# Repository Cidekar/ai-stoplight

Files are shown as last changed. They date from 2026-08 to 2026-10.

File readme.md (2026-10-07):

# Stoplight

**Stop alt-tabbing to see if your agent is done.**

```
        ╭───────────╮
        │           │
        │    ( ● )  │  ← RED     needs you
        │           │
        │    (   )  │    yellow  working
        │           │
        │    (   )  │    green   done
        │           │
        ├───────────┤
        │ ▪ ● · ·   │
        │ auth-api  │  ← which job is waiting
        ╰───────────╯
```

A small traffic light that sits on your desk and tells you, without you looking for it, exactly what every AI coding session is doing.

You know the loop. You give an agent a task, switch to something else, and then spend the next ten minutes half-wondering. You tab back. Still thinking. You tab back again. It finished four minutes ago and has been waiting on a yes.

Stoplight ends that. The answer is on your desk, in your peripheral vision, in a colour you can read from across the room.

**It is not tied to any one AI tool.** Stoplight speaks [an open protocol](rfc.md): four events over one HTTP endpoint. Claude Code, Codex, Gemini CLI, Cursor, Aider, DeepSeek, Kimi, an agent you wrote this morning, or a build that takes twenty minutes — if it can make a web request, it can drive the light. Claude Code ships with an adapter because it was first, not because it is special.

## Why you want one

**It uses the eye you are not using.** A notification competes with your screen. A light on your desk does not. You catch red the way you catch a car's brake lights, without deciding to look.

**It knows which project.** Three sessions running, one goes red. The screen below the lamps tells you it is `auth-api`, not the refactor you actually care about. Names scroll, the screen rotates, and one button pins whichever one you are watching.

**It never lies to you.** The lamp always shows the most urgent state across every session. Pin the screen, walk away, come back — if anything needs you, it is still red.

**You build it in an evening.** One board the size of a stamp, three LEDs, a battery. The case prints in four parts. No soldering iron heroics required.

**It runs itself.** One install command, then it starts with your laptop and stays out of your way. No terminal window to babysit.

**It is not tied to one vendor.** Four events over HTTP is the whole integration. If your agent can make a web request, it can drive the light.

## How it works

Three pieces, and you only ever touch the first one.

```
   ANY PRODUCER               RELAY                     THE LIGHT
   ────────────               ─────                     ─────────
   any LLM CLI ──┐
   your agent  ──┤                        USB        ┌───────────┐
   a test suite──┼── HTTP ──▶  one Go   ─serial─▶    │  ( ● )    │
   a slow build──┤             binary                │  (   )    │
   a deploy    ──┘             tracks   ╌╌╌BLE╌╌▶    │  (   )    │
                               every     or wired    │ auth-api  │
     "I am working"            session               └───────────┘
     "I need a human"          at once                on your desk
     "I am done"
```

USB serial and BLE both work. The relay auto-discovers a USB light, and `--ble` runs it against a Bluetooth light instead. The two transports sit behind one interface, so a producer sees no difference either way.

Nothing in that left column is privileged. They all send the same four events to the same endpoint, and the relay weighs them identically.

**Your agent reports what happened.** Four events: started, blocked, finished, ended. Nothing else. It never picks a colour, because it cannot know what else is running.

**One small Go binary decides what matters.** It tracks every session from every tool at once and resolves them to a single answer. Red beats yellow beats green, always. No web server to configure, no database, no config file to hand-write.

**The light does the telling.** Awake the moment something changes. It connects over USB serial or BLE, so you can wire it or run it from the battery.

Here is one moment, end to end:

```
   your agent hits a permission prompt
                  │
                  ▼
      POST {"event":"blocked",          ● RED
            "label":"auth-api"}   ──▶   + "auth-api" on screen
                  │
                  ▼
   you glance up, already know which job, and act
```

Unplug the light, kill the relay — your work never notices. Every client discards errors by design. The light is an accessory, never a dependency.

## Works with anything

Three ways in, depending on what your tool gives you.

| Your tool | What you do |
|---|---|
| Has a hook or plugin system | Use an adapter, or write one. `stoplight install` sets it up. |
| You can run a command around it | Wrap it in five lines of shell |
| You wrote it yourself | Post directly at the points where you know your state |

**With an adapter.** Claude Code ships with one, so `stoplight install` wires it up and you are done. Adapters for other tools are the most welcome contribution to this project.

**By wrapping.** Works for any command, including ones with no hooks at all. Yellow while it runs, green if it succeeds, red if it does not:

```bash
stoplight_run() {
  local id="wrap:$$" label="${PWD##*/}"
  _sl() { curl -s -m 0.25 -X POST http://127.0.0.1:7373/v1/session \
    -H 'Content-Type: application/json' \
    -d "{\"session_id\":\"$id\",\"event\":\"$1\",\"label\":\"$label\"}" \
    >/dev/null 2>&1 || true; }
  _sl started; "$@"; local rc=$?
  [ $rc -eq 0 ] && _sl finished || _sl blocked
  return $rc
}

stoplight_run my-agent --do-the-thing
stoplight_run make integration-test
```

**By posting directly.** One request, no library, no dependency:

```bash
curl -s -m 0.25 -X POST http://127.0.0.1:7373/v1/session \
  -H 'Content-Type: application/json' \
  -d '{"session_id":"job-1","event":"blocked","label":"auth-api"}' || true
```

That is the entire integration surface. The `|| true` is deliberate and it is the rule for every client: if the light is unreachable, your work carries on as though nothing happened.

Full specification in [RFC 1](rfc.md), with reference clients in shell, Python and Go.

## Setup

```
stoplight install     # adapters for what you have, plus a service at login
```

One command. It wires up an adapter for every agent built into the binary, installs a background service, and starts it. `stoplight uninstall` reverses all of it. Both are idempotent, so running them twice changes nothing. Pass `--ble` or `--ble-name <name>` to pin the service to a Bluetooth light.

For Claude Code that means five hook entries in `~/.claude/settings.json`. For anything else, point it at the endpoint and there is nothing to install at all.

After that the light works without you thinking about it. `stoplight` on its own runs the relay in the foreground, which is what you want while developing or debugging, but the service means you never have to.

## Running as a service

A light that needs a terminal window open is a light you will forget to start. The relay therefore runs as a background service that survives logout, reboot and crashes.

Each platform has one obvious mechanism, and Stoplight uses it rather than shipping its own daemon manager.

| Platform | Mechanism | Location |
|---|---|---|
| macOS | launchd user agent | `~/Library/LaunchAgents/com.stoplight.relay.plist` |
| Linux | systemd user unit | `~/.config/systemd/user/stoplight.service` |
| Windows | Scheduled task, at logon | Task Scheduler |

All three are user-level, not system-level. The relay needs no privileges, it needs your session's access to the USB device, and a user service starts when you log in rather than at boot. Installing to the system would ask for a password and gain nothing.

`RunAtLoad` and `KeepAlive` are both set on macOS, with the equivalents elsewhere. If the relay crashes, the service manager restarts it. If the light is unplugged, the relay stays up and keeps retrying rather than exiting, because exiting would look identical to a crash.

Logs go to `~/.local/state/stoplight/stoplight.log`, or the platform equivalent. The relay records lifecycle events: when it starts listening, when the light connects or drops and reconnects, when a poll or a send fails, and when an ingest is rejected. A successful event is not logged line by line, because that would fill the file on a busy desk. The service appends to that one file and nothing rotates it yet, so truncate it yourself if it grows. Rotation is planned.

### Managing it

| Command | What it does |
|---|---|
| `stoplight status` | Service state, light connection, session count and aggregate |
| `stoplight restart` | Bounce the service |
| `stoplight logs` | Tail the log |
| `stoplight service stop` | Stop until next login |
| `stoplight service disable` | Stop and do not start at login |

These wrap the platform tool rather than replacing it. `launchctl` and `systemctl` still work directly if you prefer them, and `stoplight status` prints the underlying command it used so the wrapper is never a black box.

### Producers and the relay are independent

Producers post and forget. If the relay is not running, the post fails and the producer carries on. `stoplight notify` exits 0 on every path, and the reference clients in RFC 1 discard errors deliberately.

That independence matters during upgrades and crashes. Your agent keeps working whether or not the light does, and the relay can be restarted underneath a running session without losing anything except the moments it was down.

Recovery runs one way only: from the relay down to the light. The relay holds the session set in memory and re-sends the current frame the moment the light comes back, so the lamps catch up without anyone asking the producers for anything. The relay never calls back to a producer, because it holds no address for one. That is also the limit of the recovery: restart the relay itself and the session set is gone, and each session reappears only when its producer next reports. [RFC 1 §7](rfc.md#7-session-lifecycle) asks long-running agents to re-send their state every few minutes for exactly this reason.

## Events

A producer reports what happened. It never picks a colour, because it cannot know what else is running. Four events cover everything:

| Event | Colour | Meaning |
|---|---|---|
| `started` | Yellow | Working |
| `blocked` | Red | Needs a human |
| `finished` | Green | Done |
| `ended` | — | Stop tracking this session |

The distinction that carries the whole product is `blocked` versus `started`. Send `blocked` when a human has to act before anything continues. Send `started` when the agent is thinking or running tools on its own.

### Claude Code

The adapter maps Claude Code's hooks onto those events. This is the only place a vendor's vocabulary appears:

| Claude Code hook | Matcher | Event |
|---|---|---|
| `SessionStart` | `startup` | `idle` |
| `UserPromptSubmit` | | `started` |
| `PreToolUse` | | `started` |
| `Notification` | `permission_prompt` | `blocked` |
| `Stop` | | `finished` |
| `SessionEnd` | | `ended` |

The matcher keeps a hook to the sub-event that means the event. `SessionStart` fires on more than a fresh start, so it is pinned to `startup`, or an auto-compaction mid-turn would read as idle. `Notification` fires on more than a permission prompt, so it is pinned to `permission_prompt`, or a routine idle reminder would turn the light red. `PreToolUse` carries the `started` that clears `blocked`: after you approve a prompt the agent runs a tool, and this is what returns the session to working before the turn ends.

`SessionEnd` is what makes a closed session leave the light. It fires on exit, on Ctrl-D and on abnormal termination.

Adding another agent is a new adapter, or no adapter at all if it can post directly. See [RFC 1 §10](rfc.md#10-adapters).

#### Hooks report changes, a poll fills the gaps

The hooks are edge-triggered: they fire on a transition, never on a state. On their own they miss two things. A session that was open before the relay started has no transition to announce itself with. A window that is killed with `kill -9`, a closed terminal or a crash skips `Stop` and `SessionEnd`, so the session stays in the relay at whatever colour it held.

The Claude Code adapter closes both gaps with a poll. It reads `claude agents --json` every twenty seconds and declares the whole live set to the relay as a sync, per [RFC 1 §5.4](rfc.md#54-the-sync-endpoint). A session the agent already runs appears in the next poll and the light learns it exists. A session that vanished without a final event is absent from the next poll and the relay ends it. One poll after a relay restart restores the whole picture.

The poll corrects, it does not replace the hooks. A hook moves the lamp the instant something changes, which is the whole point of the device. The poll runs on its own schedule and never sits on the hook path. See [RFC 1 §10.1](rfc.md#101-discovery-mechanisms).

For a producer that only reports and cannot be polled, a stale red session clears by hand. Sessions carry a `last_seen` timestamp, visible in `GET /v1/status`, so a stale entry is the one whose `last_seen` stopped moving. End it with its id:

```bash
curl -s -X POST http://127.0.0.1:7373/v1/session \
  -H 'Content-Type: application/json' \
  -d '{"session_id":"<the stale id>","event":"ended"}'
```

Restarting the relay also clears everything, since the session set lives in memory.

## State model

All sessions share one light, whatever produced them, and the most urgent state wins.

```
red  >  yellow  >  green
```

If any session needs a human, the light is red. Otherwise, if any session is working, the light is yellow. Otherwise it is green. No live sessions at all means the lamps are off, because green means finished and off means nothing is running.

The relay tracks each session separately and computes the aggregate. A Claude Code session and a shell script are weighted identically; the light does not care which tool asked. Sessions that end are dropped, and a session that goes quiet expires after 30 minutes so one crash cannot hold the light red forever.

## Task display

The lamps tell you the state. The screen tells you which job that state belongs to. This matters as soon as you run more than one session, because a red light with no context does not say which project is waiting on you.

A producer can send a label. If it does not, the relay derives one.

```
·
auth-api
```

The header is a row of dots, one per session, with the current one filled. Below it the screen draws the label. The screen carries no state word, because the lamps already say the state in colour from across the room. The derived label is the git branch of the session's working directory, falling back to the directory name, then the provider name, then the session ID. Branches are usually named after the work, so this is free and it is usually right. A detached HEAD has no branch name, so it falls through to the directory name like any other case.

A producer can send its own instead, and you can override any session by hand.

```
stoplight task --session-id <id> "nightly integration run"
stoplight task --session-id <id> --clear
```

That overrides the label until the session ends or you clear it. `--clear` removes the override, so the derived label shows again.

The session ID is not optional. There is no "current session" concept yet, because nothing tells the CLI which of your sessions the terminal you are typing in belongs to, so the command asks you which one you mean. `stoplight status` prints a session count, not the ids; read the ids from `GET /v1/status`, which lists each session with its `id`.

### Rotation

With more than one session running, the screen cycles through them. Each session gets the screen for at least three seconds, then the display advances.

Order is by session start time, so a session keeps its place in the cycle as others come and go. A single session does not rotate, because a cycle of one is a static screen that redraws for no reason. The row of dots in the header shows position in the set: one dot per session, the current one filled. The shape of the row says both how many sessions there are and where you are in the cycle, without the eye reading two digits.

```
▪  ● · · ·
stoplight
```

Two rules keep rotation from hiding things.

The lamps never rotate. They always show the aggregate of every session, so a red lamp means something needs you even while the screen displays a green session. The lamp answers whether anything wants attention and the screen answers what is running. Those are different questions and the device answers both at once.

When a session turns red, the screen jumps to it immediately and holds for a full interval before resuming the cycle. The moment something needs you is the moment you want to know which project it is.

### Scrolling

The label line holds about eight characters, which is narrower than many branch names. Labels that do not fit scroll.

Scrolling is a marquee, not a loop. The label holds at the start for a second, scrolls left at a readable rate, holds at the end, then resets. A continuous wrap-around never gives a stable moment to read the first characters, which is where the useful part of a branch name usually is.

Two limits keep it calm. Labels that already fit are drawn statically and never move. Scrolling resets to the start whenever the session changes colour.

Rotation waits for scrolling. The three second interval is a minimum, not a fixed period, so a slot holds until its label has finished scrolling and then advances. Rotation therefore runs slightly irregularly, paced by content rather than a clock.

Before scrolling, the app strips common prefixes from the derived label. `feature/`, `bugfix/`, `hotfix/` and `worktree-` carry no information when every branch has one. `worktree-stoplight-readme` becomes `stoplight-readme`, which is shorter and more distinct.

### Button

One button on the case, wired to a spare GPIO and ground, using the internal pull-up. Firmware debounces it over about 50ms.

| Press | Action |
|---|---|
| Short, under 500ms | Pin or unpin the session on screen |
| Long, 500ms or more | Advance to the next session |

Pinning stops the rotation on the current session. Scrolling continues, because a pinned label still needs to be readable. A marker in the corner shows the pin.

A pin releases itself. It clears when that session ends, and it clears after a timeout even if the session is still alive. Without expiry you could pin something on a Monday, forget, and quietly stop seeing every other session for a week.

Pinning changes the screen and never the lamps. A pinned green session with a red session running still gives a red lamp. The pin must not be able to hide an alert.

The pin lives in the firmware, so it survives a dropped link and reconnection over either transport. It is a property of the device rather than of the session list, which is what lets it survive a dropped BLE link too.

Long press was chosen over a double tap. A double tap needs a timing window between presses, and pressing a button set into a small case rocks the case on the desk, which makes that window unreliable. A long press has no window, only a duration, and a missed long press reads as a short press instead of doing nothing visible.

## Protocol

Two hops. Producers talk to the relay over HTTP, specified in [RFC 1](rfc.md). The relay then talks to the light, described here.

```
  any producer ──HTTP──▶ relay ──serial or BLE──▶ light
                 RFC 1            frame format below
                 public           private, may change
```

Only the first hop is a public contract. The frame format below is between this relay and this firmware, and can change without breaking a single producer.

One JSON object per line, newline-terminated. The format is transport-agnostic on purpose: serial sends each line over the wire and BLE sends the same line over a characteristic, and the firmware parses one format either way.

The relay sends the whole session list on every change, not one line of text.

```json
{"color":"red","sessions":[
  {"id":"a1","label":"stoplight-readme","state":"needs you","color":"red"},
  {"id":"b2","label":"adele-api","state":"working","color":"yellow"}
]}
```

| Field | Values | Notes |
|---|---|---|
| `color` | `red`, `yellow`, `green`, `off` | Aggregate. Drives the lamps. |
| `sessions` | array | One entry per active session, ordered by start time |
| `sessions[].id` | any string | Stable for the life of the session |
| `sessions[].label` | any string | The label line. Scrolled by the firmware if it overflows. |
| `sessions[].state` | any string | Carried for compatibility. The firmware stores it but no longer draws it; the lamps show the state. |
| `sessions[].color` | `red`, `yellow`, `green` | This session's own state |

Every field is optional. A message carrying only `color` moves the lamps and leaves the screen alone. Unknown fields are ignored, so the app and firmware can be updated independently.

Sending the full list rather than rotation frames keeps the link quiet and puts rotation, scrolling and pinning in the firmware, where they keep working if the link drops. That matters little over a wire and matters a great deal over a radio, which is why the format was chosen this way. The `id` field is what lets a pin survive an update to the list.

The screen is monochrome and holds about eight characters on the label line. Colour lives in the lamps, not the display.

JSON costs a few bytes over a single-character protocol and pays that back the first time you open a serial monitor and can read what is happening.

## Hardware

The light is an ESP32 with BLE hardware, three LEDs, a screen, and a LiPo battery. The firmware talks over USB serial or BLE. The radio and the cable carry the same frames, so you choose the link at the relay.

### Board

The board is an **ESP32-C3 SuperMini with 0.42 inch OLED**.

It is 25 × 20.5mm, roughly a postage stamp, with a 72×40 OLED soldered on and a ceramic BLE antenna. The screen is part of the board, so there is no separate display module and no I²C wiring. Thirteen GPIOs are broken out, which is far more than the three the lamps need.

The screen is small. The lit area is 9.2 × 5.2mm. The firmware draws two rows: a header of position dots and one label line of about eight characters. That is enough for a branch name, which is all the label needs to be. It is a status light, not a terminal.

The board has no charging circuit, so a TP4057 module supplies one for three wires.

The panel is a 72×40 display driven by an SSD1306 controller that addresses a 128×64 buffer, so the visible window sits at a column offset of 28. Use the `U8G2_SSD1306_72X40_ER_F_HW_I2C` constructor in U8g2, which applies the offset for you. A generic 0.42 inch driver renders off-screen and looks like a dead panel. I²C is on GPIO 5 for `SDA` and GPIO 6 for `SCL`, at address `0x3C`.

Flash it as `ESP32C3 Dev Module` with `USB CDC On Boot` enabled, 4MB flash, QIO mode.

### Bill of materials

Nine parts, one order, and you probably own three of them already.

| Item | Qty | ASIN | Notes |
|---|---|---|---|
| ESP32-C3 SuperMini with 0.42 inch OLED | 1 | `B0H2GWGP9Q` | 5 pack. BLE, USB-C, screen built in. |
| TP4057 charging module, USB-C | 1 | `B0CDWZ9MDC` | 5 pack. 1A, protection built in. |
| LiPo battery, 500mAh, 503035 | 1 | `B0BJPG4B72` | 35 × 30 × 5mm, protection board built in |
| 220Ω resistors, ¼W | 3 | `B08QRFCMC9` | 100 pack, metal film, ±1% |
| 5mm LEDs, red, yellow, green | 3 | | Common enough to have already |
| Momentary button | 1 | | Pin and advance. A 6 × 6mm tactile switch is typical. |
| USB-C data cable | 1 | | Must carry data for flashing. Charge-only cables enumerate nothing. |
| Slide switch, SPDT | 1 | | Optional. Cuts battery drain when the light is put away. |
| Perfboard and 30AWG wire | 1 | | For the permanent build. Thin wire: the cavity is small. |

The boards, charging modules and resistors only sell in multipacks, so one order builds about five lights. Treat the spares as insurance, because these parts are cheap and easy to kill with a soldering iron.

Add a half-size breadboard and jumper wires if you want to test before soldering. Worth it.

Check the ASIN and the size selector at checkout. Suppliers list many values, pack sizes and connector types under near-identical titles, and the resistor pack in particular chooses its resistance through a size option.

The battery is the only part with no substitute on hand, and cell listings often ship slowly. Order it first, or accept that it arrives last. Nothing early in the build needs it, because the board runs from USB while you write firmware.

### Wiring

The screen needs no wiring. It is soldered to the board and the firmware drives it over I²C on GPIO 5 and 6, which are committed to the display.

That leaves the LEDs. Each anode connects through a 220Ω resistor to a GPIO pin. All cathodes share a common ground rail.

```
   ESP32-C3 SuperMini
   ┌───────────────────┐
   │ ▉▉ 0.42" OLED  ▉▉ │      220Ω goes BEFORE the LED anode
   │                   │      ──────────────────────────────
   │ Soldered on. I²C  │      long leg  = anode  = resistor side
   │ on GPIO 5 and 6.  │      short leg = cathode = ground side
   │ No wiring at all. │
   │                   │                      long       short
   │                   │                        ╷          ╷
   │                   │                    ╭───┴──────────┴─────╮
   │           GPIO 0  ├──────▉▉▉▉──────────┤   ● RED            ├────┐
   │                   │                    ╰────────────────────╯    │
   │                   │                    ╭───┴──────────┴─────╮
   │           GPIO 1  ├──────▉▉▉▉──────────┤   ● YELLOW         ├────┤
   │                   │                    ╰────────────────────╯    │
   │                   │                    ╭───┴──────────┴─────╮
   │           GPIO 2  ├──────▉▉▉▉──────────┤   ● GREEN          ├────┤
   │                   │                    ╰────────────────────╯    │
   │                   │                                              │
   │           GPIO 3  ├───────o   o────────────────────┐             │
   │                   │       button, no resistor      │             │
   │                   │                                │             │
   │           GND     ├────────────────────────────────┴─────────────┘
   └─────┬─────────────┘                one common ground rail
         ╧
       USB-C
```

| LED | GPIO |
|---|---|
| Red | 0 |
| Yellow | 1 |
| Green | 2 |

The button goes to GPIO 3 and ground. No resistor: the firmware enables the internal pull-up, so the pin reads high until the button pulls it low.

Avoid GPIO 5 and 6, which drive the screen, and GPIO 8 and 9, which carry the onboard LED and the boot strapping. Confirm the numbers against your board pinout before soldering.

Polarity matters. The long leg of an LED is the anode and goes toward the resistor and GPIO pin. The short leg is the cathode and goes toward ground. Backwards, the LED stays dark.

Breadboard the circuit before you solder it. The enclosure dimensions have never been checked against real parts, and a reversed LED on a breadboard costs seconds. [firmware/readme.md](firmware/readme.md#prove-each-led-after-wiring) gives a three-command sequence that lights red, then yellow, then green, so a miswired LED names itself.

Power runs through the charging module. The battery connects to the `B+` and `B-` pads, and the module's `OUT+` and `OUT-` feed the board's `5V` and `GND` pins. Put the optional slide switch in the `OUT+` line. Charge over the module's own USB-C port, and use the board's USB-C port for flashing.

Check the silkscreen before soldering. Pad names vary between the TP4056 and TP4057 and between suppliers, and some boards label the load side `+` and `-` only. Getting the battery backwards destroys the module.

A 1A module charges a 500mAh cell at about 2C, which is faster than the cell prefers. The protection circuit makes this safe rather than ideal, and the module runs warm while charging. Lower the programming resistor if your board has one, or accept a fast charge and a warm module.

### Power

BLE is what lets this run on a battery. Over USB the cable powers the light as well as carrying its frames; over BLE the cell carries it alone. The parts list already covers the battery build.

The radio idles at a few milliamps, so the LEDs dominate the draw. A 500mAh cell should give a day or two of use, because only one lamp is lit at a time and the light is idle for most of a working day. That is arithmetic, not measurement.

Two things extend it. The firmware dims the LEDs with PWM rather than driving them at full current, which costs nothing visually behind a diffuser. It also blanks the screen after a period with no updates and wakes it on the next message.

The C3 has no fuel gauge, so the firmware cannot report a true battery percentage. If that matters more than size, the TFT Feather has a MAX17048 and reports real numbers. A larger cell also fits: a 603443 at 1000mAh is 43 × 34 × 6mm and still clears the bay with a 2mm deeper body.

## Enclosure

Four printed parts: a body, three lens inserts, a back cover, and a button plunger. About **36 × 78 × 18mm**, roughly a matchbox standing upright.

```
     ┌───────────────┐
     │      ( )      │   recessed button, found by touch
     ├───────────────┤
     │   ╲ ╭─────╮   │
     │     │  ●  │ R │   visors hood each lamp
     │   ╲ ╰─────╯   │
     │     ╭─────╮   │   battery hides upright
     │   ╲ │  ●  │ Y │   behind the lamp column
     │     ╰─────╯   │
     │   ╲ ╭─────╮   │
     │     │  ●  │ G │
     │     ╰─────╯   │
     ├───────────────┤
     │  ┌─────────┐  │
     │  │ ● · ·   │  │   board clips into printed rails
     │  │ auth-api│  │   no screws
     │  └─────────┘  │
     └───────────────┘
       ├── 36mm ──┤
```

The body takes a few hours to print. A lens takes two minutes, which is why you print one first to check your printer's tolerances before committing to the rest.

Everything else — dimensions, print settings, the parametric source, and the STLs — is in **[`enclosure/`](enclosure/readme.md)**.

## Layout

```
main.go               entry point and command dispatch
internal/stoplight/   state machine, session tracking, aggregation
internal/relay/       the long-running process, HTTP and socket ingest
internal/adapter/     one package per agent, claudecode is the first
internal/service/     launchd, systemd and scheduled task install
internal/transport/   USB serial and BLE, each behind one interface
internal/light/       virtual light for development
internal/notify/      the one-shot client used by hooks
firmware/             ESP32 firmware
```

Transports sit behind one interface, so nothing above it cares which is connected. `internal/transport/serial` and `internal/transport/ble` each implement that interface, and nothing above them changes when you switch link. The virtual light implements the interface too and prints to the terminal, so the whole system is testable without hardware.

Adding another agent means adding a package under `internal/adapter/`. Nothing else changes, and agents that can post directly need no adapter at all.

Full detail in [design.md](design.md).

## Commands

| Command | What it does |
|---|---|
| `stoplight install` | Hook entries, service, and start it. The only setup step. |
| `stoplight uninstall` | Remove the hooks and the service |
| `stoplight` | Run the relay in the foreground. For development. |
| `stoplight status` | Service state, light connection, session count and aggregate |
| `stoplight restart` | Bounce the service |
| `stoplight logs` | Tail the log |
| `stoplight service stop` | Stop until next login |
| `stoplight service disable` | Stop and do not start at login |
| `stoplight task --session-id <id> <text>` | Override the screen label for that session |
| `stoplight task --session-id <id> --clear` | Remove the override and show the derived label again |
| `stoplight notify <event>` | One-shot. Called by hooks, not by you. |
| `stoplight help` | The same command list, printed |

Flags on the bare relay command:

| Flag | What it does |
|---|---|
| `--virtual` | Use the virtual light instead of hardware |
| `--serial <path>` | Use a specific serial device instead of auto-discovering one |
| `--ble` | Use a Bluetooth light instead of a USB one |
| `--ble-name <name>` | Connect to one named Bluetooth light. Implies `--ble`. |
| `--addr <host:port>` | HTTP listen address, default `127.0.0.1:7373` |
| `--timeout <duration>` | Session silence timeout, default `30m` |

The transport flags `--virtual`, `--serial` and `--ble` are mutually exclusive. With none of them, the relay looks for a serial light, then a Bluetooth light, then falls back to the virtual one, saying so each step, because a silent fallback looks exactly like broken hardware. `status` and `task` take `--addr` too, for a relay on a non-default port.

## Build it

| | |
|---|---|
| [`rfc.md`](rfc.md) | **RFC 1** — the protocol. Read this to connect your own agent. |
| [`design.md`](design.md) | State machine, Go types, package layout, internals |
| [`enclosure/`](enclosure/readme.md) | Printable case: OpenSCAD source, STL generator, and the STLs |
| [`roadmap.md`](roadmap.md) | Project status, build order, and the decisions behind it |
| [`CONTRIBUTING.md`](CONTRIBUTING.md) | How to work on the app, an adapter, the firmware, or the case |

You do not need the hardware to start. The Go app ships with a virtual light that renders to your terminal, so most of the project is testable on a laptop with nothing plugged in.

## License

[Apache License 2.0](LICENSE). Copyright 2026 Cidekar, LLC.

Build it, sell it, put it on your desk at work. The licence asks only that you keep the notice and state what you changed.

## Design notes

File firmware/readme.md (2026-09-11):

# Firmware

ESP32 firmware for the Stoplight device. Three LEDs show the aggregate state of every AI session, and a 0.42 inch OLED shows which session that state belongs to.

The firmware owns rotation, scrolling and the pin, so all three keep working when the link to the relay drops. See [design.md](../design.md), "What the firmware owns".

## Read this first: the screen offset

**This is the single thing that will cost you an evening.**

The 0.42 inch OLED is a 72×40 window driven by an SSD1306 that addresses a **128×64** buffer. The visible area sits at a **column offset of 28** inside that buffer. Draw at `0,0` with a generic 128×64 driver and the pixels land outside the window. The panel then looks completely dead: no flicker, no partial text, nothing. It is indistinguishable from a broken screen or a wiring fault, which is why people spend hours on it.

These are the values U8g2 applies for this panel. They are read from `u8x8_d_ssd1306_72x40.c` in the library source, and the rendering they produce is confirmed on hardware:

| Value | Measured |
|---|---|
| `default_x_offset` | 28 |
| `flipmode_x_offset` | 28 |
| `tile_width` | 9 tiles, so 72 pixels |
| `tile_height` | 5 tiles, so 40 pixels |
| Visible area | 72×40 |

The offset is horizontal only. There is no vertical offset to apply: the panel uses the first five tile rows of the buffer, so the y origin is 0.

Use this constructor and nothing else. It applies the offset for you.

```cpp
U8G2_SSD1306_72X40_ER_F_HW_I2C u8g2(U8G2_R0, U8X8_PIN_NONE);
```

| Part of the name | Meaning |
|---|---|
| `72X40_ER` | The correct panel geometry, including the offset |
| `F` | Full frame buffer. Needed for smooth scrolling. |
| `HW_I2C` | Hardware I²C, which is what this board wires up |

If you copy a constructor from a generic SSD1306 tutorial, it will be `128X64_NONAME` and your screen will stay dark. That is the bug.

## Flashing

```bash
cd firmware
make setup     # first run only
make flash
make monitor
```

That is the whole flow. `make` on its own lists every target.

| Target | Does |
|---|---|
| `help` | List the targets, and print the FQBN and the detected port. The default. |
| `setup` | Install the ESP32 core and U8g2 |
| `compile` | Compile the sketch |
| `upload` | Upload the last build |
| `flash` | `compile` then `upload` — the one you want |
| `monitor` | Open the serial console at 115200 |
| `test` | Run the host checks under ASan/UBSan, no board needed |
| `board-details` | Print the board's real menu options, to check the FQBN |
| `ports` | List the serial ports arduino-cli can see |
| `clean` | Remove the build directories |

**`make setup` downloads a few hundred MB** of Xtensa/RISC-V toolchain the first time, and takes a while on a slow link. It runs once per machine, not once per checkout. Everything after it is fast.

The Makefile needs `arduino-cli`, which it will not install for you. If it is missing, every target that needs it stops and prints `brew install arduino-cli` rather than failing with a bare "command not found". Installing a toolchain is your call, so `make setup` only runs the arduino-cli-internal steps once the CLI itself exists.

**The port is auto-detected** as the first `/dev/cu.usbmodem*`. Override it with `PORT=`:

```bash
make flash PORT=/dev/cu.usbmodem1101
```

If no port is found, the most likely cause by a wide margin is a **charge-only USB-C cable**. It enumerates nothing at all and is physically identical to a data cable. The error message says so, because this is the failure that wastes an afternoon.

### Why a Makefile rather than the IDE

The board settings that matter are not defaults, and one of them is silently wrong more often than it is right. The Makefile puts them in a single FQBN, defined once:

```
esp32:esp32:esp32c3:CDCOnBoot=cdc,FlashSize=4M,FlashMode=qio
```

`CDCOnBoot=cdc` is the FQBN form of **USB CDC On Boot: Enabled**. It is the setting people miss in the GUI, and the reason a command-line flow is better here. Left at its default the board still enumerates and still uploads, so nothing looks wrong — but `Serial` goes to the hardware UART pins instead of USB. The monitor stays empty, no frames ever arrive, and the device looks dead. In a Makefile the setting is reviewable and cannot be forgotten; in a Tools menu it is one dropdown among twelve.

Override the whole FQBN with `FQBN=` if your module differs, for example an 8MB flash part. `make board-details` prints the menu keys and values your installed core actually accepts.

### Fallback: the Arduino IDE

If you prefer a GUI, the same build is these settings under Tools. Flash as **ESP32C3 Dev Module**.

| Setting | Value |
|---|---|
| Board | ESP32C3 Dev Module |
| USB CDC On Boot | **Enabled** |
| Flash Size | 4MB (32Mb) |
| Flash Mode | QIO |
| Partition Scheme | Default 4MB with spiffs |
| Upload Speed | 921600 |

`USB CDC On Boot` must be **Enabled**, for the reason above. This is the second most common way to lose an hour on this board, after the screen offset.

Install the library by hand too: Tools -> Manage Libraries, search `U8g2`, install the one by *oliver*.

## Libraries

One dependency, which `make setup` installs:

| Library | Install |
|---|---|
| U8g2 by oliver | Library Manager, search "U8g2" |

There is no JSON library in that list, which is deliberate. The frame parser is hand written, for the reasons in [Parsing](#parsing) below.

There is no Bluetooth library either, and that is not an omission. `BLE` ships inside the ESP32 core, so the radio needs nothing installed beyond what `make setup` already fetches.

## The fastest smoke test

This needs **no wiring at all** — the screen is soldered to the board, so a bare board and a data cable are the whole rig. It is the quickest way to prove a flash worked.

```bash
cd firmware
make flash
make monitor
```

Paste this one line and press enter:

```json
{"color":"red","sessions":[{"id":"a","label":"auth-api","state":"needs you","color":"red"}]}
```

The screen shows `auth-api` and `needs you`. That is a working flash: USB CDC is on, I²C is up, the constructor offset is right and the parser runs. If you have wired the LEDs, the red one lights as well.

Nothing on screen? Go to [The screen is completely blank](#the-screen-is-completely-blank). An empty monitor instead means USB CDC On Boot is not enabled — reflash with `make flash`, which sets it.

## Wiring

The screen needs no wiring. It is soldered to the board and driven over I²C on GPIO 5 and 6. Three LEDs and one button are the whole job.

```
   ESP32-C3 SuperMini
   ┌───────────────────┐
   │ ▉▉ 0.42" OLED  ▉▉ │      220Ω goes BEFORE the LED anode
   │                   │      ──────────────────────────────
   │ Soldered on. I²C  │      long leg  = anode  = resistor side
   │ on GPIO 5 and 6.  │      short leg = cathode = ground side
   │ No wiring at all. │
   │                   │                      long       short
   │                   │                        ╷          ╷
   │                   │                    ╭───┴──────────┴─────╮
   │           GPIO 0  ├──────▉▉▉▉──────────┤   ● RED            ├────┐
   │                   │                    ╰────────────────────╯    │
   │                   │                    ╭───┴──────────┴─────╮
   │           GPIO 1  ├──────▉▉▉▉──────────┤   ● YELLOW         ├────┤
   │                   │                    ╰────────────────────╯    │
   │                   │                    ╭───┴──────────┴─────╮
   │           GPIO 2  ├──────▉▉▉▉──────────┤   ● GREEN          ├────┤
   │                   │                    ╰────────────────────╯    │
   │                   │                                              │
   │           GPIO 3  ├───────o   o────────────────────┐             │
   │                   │       button, no resistor      │             │
   │                   │                                │             │
   │           GND     ├────────────────────────────────┴─────────────┘
   └─────┬─────────────┘                one common ground rail
         ╧
       USB-C
```

| Part | GPIO | Notes |
|---|---|---|
| Red LED | 0 | anode -> 220Ω -> GPIO |
| Yellow LED | 1 | anode -> 220Ω -> GPIO |
| Green LED | 2 | anode -> 220Ω -> GPIO |
| Button | 3 | to ground, internal pull-up, no resistor |
| OLED SDA | 5 | on board, do not reuse |
| OLED SCL | 6 | on board, do not reuse |

All three LED cathodes share a common ground rail. I²C address is `0x3C`.

**Avoid GPIO 5 and 6** (the screen) and **GPIO 8 and 9** (the onboard LED and boot strapping). Pulling GPIO 9 low at boot puts the chip into download mode.

**Polarity matters.** The long leg of an LED is the anode and goes toward the resistor and the GPIO pin. The short leg is the cathode and goes to ground. Backwards, the LED simply stays dark.

**Breadboard it first.** Build the circuit on a breadboard before you solder anything. The enclosure dimensions have never been checked against real parts, so the fit is unproven — see [Still unverified](#still-unverified-everything-that-needs-parts-not-yet-attached). A breadboard also makes a reversed LED a five-second fix rather than a desoldering job.

### Prove each LED after wiring

Run the relay against the board, then force each colour in turn. A miswired or reversed LED shows up at once, because you already know which lamp is meant to be lit.

```bash
go build -o /tmp/sl .
/tmp/sl --serial /dev/cu.usbmodem2101 --addr 127.0.0.1:7413
```

Leave that running and open a second terminal. These commands light red, then yellow, then green:

```bash
post() {
  curl -s -m 2 -X POST http://127.0.0.1:7413/v1/session \
    -H 'Content-Type: application/json' -d "$1"
}

post '{"session_id":"w","event":"blocked","label":"wiring"}'   # RED
post '{"session_id":"w","event":"started","label":"wiring"}'   # YELLOW
post '{"session_id":"w","event":"finished","label":"wiring"}'  # GREEN
post '{"session_id":"w","event":"ended"}'                      # all dark
```

Exactly one lamp is lit at each of the first three steps. Anything else is a wiring fault, and the step that fails names the pin:

| Symptom | Cause |
|---|---|
| One colour never lights, the other two do | That LED is reversed, or its resistor leg is not seated |
| The wrong colour lights | Two GPIO wires are swapped |
| No LED ever lights | The ground rail does not reach the board's `GND` pin |
| All three look dim | Correct, not a fault. `LAMP_DUTY` is 80/255 by design — see [Lamps](#lamps). |

Change `/dev/cu.usbmodem2101` to match your board; `make ports` lists what is there. Port 7413 is used so this cannot disturb a relay already running on the default. This is the shape of [Five minutes to a working light](../CONTRIBUTING.md#five-minutes-to-a-working-light) in CONTRIBUTING.md, pointed at real hardware instead of `--virtual`.

## Host tests

The parser, the rotation state machine, the lamps and the button are plain C++ that never touches a register directly, so they run on a host compiler with `Arduino.h` and `U8g2lib.h` stubbed out. That is the whole test suite, and it needs no board.

```bash
cd firmware
make test
```

That builds and runs them. `make clean` removes the build directories. `cd firmware/test && make` does the same thing directly; `test/Makefile` owns the sanitiser flags and the stub include order, and `make test` delegates to it rather than repeating them. The only requirement is a C++17 compiler with AddressSanitizer, which both clang and gcc have. No `arduino-cli` and no board.

Everything is compiled with `-Wall -Wextra -Wconversion -Wshadow` and run under `-fsanitize=address,undefined`. The sanitisers are not optional: every buffer in the firmware is fixed size and the parser is the one component that reads untrusted input, so an off-by-one is the failure mode most worth catching, and it is exactly what ASan finds and a passing assertion does not.

| Path | Holds |
|---|---|
| `test/Makefile` | The build, the flags and the sanitiser options |
| `test/test_main.cpp` | Every check |
| `test/stubs/Arduino.h` | `millis()`, GPIO and LEDC, all observable from a test |
| `test/stubs/U8g2lib.h` | The constructor and the handful of methods `display.cpp` calls |
| `test/stubs/stubs.cpp` | Storage for the simulated clock, pins and screen |

Time is set by the test rather than read from a clock, which keeps the run instant and makes the `millis()` rollover at about 49 days reachable — otherwise it is untestable in practice.

What the checks cover:

| Group | Pins |
|---|---|
| Frame sizes | 1, 4, 5 and 8 sessions all fit, and the 8-session worst case at maximum id and label length still fits `SL_LINE_MAX` |
| Oversized lines | The aggregate is recovered from a frame too long to parse **whether `color` comes before or after the sessions array**, every colour survives both orders, a per-session colour is never mistaken for the aggregate, and the reader recovers afterwards |
| UUID ids | Two UUIDs sharing a 24-character prefix stay distinct, the pin follows its own session across a reorder, and the jump to red is not suppressed |
| Duplicate ids | Two sessions sharing an id do not both take a rotation slot, the first is kept, and every id in a parsed frame is unique |
| Unknown keys | Unknown fields at any depth are skipped, an unknown colour name leaves the lamps alone, and a value too deeply nested to skip costs that one key rather than every key after it |
| Truncated input | An unterminated line never completes, and a frame with no `color` leaves the lamps exactly where they were |
| The reported failure | Five sessions with one blocked turns the lamp red, end to end through the reader, the parser, the lamps and the display |
| The invariant | Pinning, advancing and ticking for a simulated minute never move a lamp |
| Rollover | Short and long presses stay correct across the `millis()` wrap, rotation measurably keeps cycling through it, and a red hold whose deadline lands on exactly 0 is still honoured |
| Display | Rotation waits for scrolling, one session never rotates, a session keeps its slot, and a pin expires both ways |
| Strings | Over-long values truncate, escapes decode, non-ASCII collapses to a single `?`, and a `\uXXXX` escape cut off by the end of the line reads nothing past the terminator |
| BLE link | A frame reassembles at **every** byte boundary of a real frame, 20-byte chunks work, an exact multiple of the chunk size needs no empty final chunk, two frames in one write are two frames, an over-capacity chunk is dropped whole rather than truncated, a wrapping queue survives 400 frames, a truncated frame recovers on the next one, a repeated frame is idempotent, and an oversized line still surrenders its aggregate |

The suite is a regression net for real defects and it fails loudly if any is reintroduced. Reverting `SL_LINE_MAX` to 512 and `SL_MAX_ID` to 24 turns 0 failures into 28. Each later fix is pinned the same way, measured by reverting it:

| Revert | Failures |
|---|---|
| Drop the tail salvage, so only a leading `color` is recoverable | 11 |
| Restore `holdUntil_ == 0` as the "no hold" sentinel | 4 |
| Make an unskippable value abandon the rest of the frame | 5 |
| Allow duplicate ids to take a slot each | 8 |

The `\uXXXX` bounds guard is checked differently, because with it removed the code still returns the right answer — it just reads four bytes past the terminator to get there. The check parses a truncated escape out of a heap buffer sized exactly to the input, so AddressSanitizer's redzone sits immediately after the NUL and the overread is a crash rather than a silent success. On the stack or in a string literal the same overread lands in other valid memory and nothing notices, which is exactly why it survived review for so long.

## Testing without the relay

The device reads newline-delimited JSON on USB serial, so a serial monitor is a complete test harness. `make monitor` opens one at the right baud rate and sends a newline on enter. In the Arduino IDE instead, open the monitor at **115200 baud** and set the line ending to **Newline** — the parser acts on a frame when it sees the newline, so with "No line ending" selected nothing will ever happen.

For the shortest possible check see [The fastest smoke test](#the-fastest-smoke-test). Paste any of these and press enter.

Two sessions, one of them blocked. The lamp goes red and the screen rotates:

```json
{"color":"red","sessions":[{"id":"a1","label":"auth-api","state":"needs you","color":"red"},{"id":"b2","label":"stoplight","state":"working","color":"yellow"}]}
```

A long label, to watch the marquee. It holds at the start, scrolls left, holds at the end, then resets:

```json
{"color":"yellow","sessions":[{"id":"a1","label":"feature/a-very-long-branch-name","state":"working","color":"yellow"}]}
```

Lamps only. The screen is left exactly as it was:

```json
{"color":"green"}
```

Everything off. Lamps dark, screen cleared:

```json
{"color":"off","sessions":[]}
```

Forward compatibility. Unknown fields are ignored rather than rejected, so this behaves the same as the first example:

```json
{"color":"red","version":2,"meta":{"nested":[1,2]},"sessions":[{"id":"a1","label":"auth-api","state":"needs you","color":"red","future":true}]}
```

Things worth trying by hand:

- Send four sessions and watch the row of position dots follow the rotation: four dots, and the filled one moves along as the screen cycles.
- **Short press** the button to pin. A `*` appears and rotation stops, but scrolling carries on.
- **Long press** (hold half a second) to advance to the next session and restart its scroll.
- Send a frame where one session turns red. The screen jumps to it at once.
- **Pin a green session while another is red.** The lamp must stay red. That is the invariant the whole device rests on.

## Behaviour

### Layout

The 72×40 panel carries two rows, not three:

| Row | y | Content |
|---|---|---|
| Header | 0 | The pin marker `*`, then one position dot per session, in the small 5×7 font |
| Label | 14 | The session label in `u8g2_font_10x20_tf`, scrolled if it overflows |

The position dots replace the older `n/N` counter. A hollow circle is another session and a filled disc is the one on screen, so the shape of the row says both how many sessions there are and where you are in the cycle without the eye having to read and compare two digits. **One session draws no dots at all**, matching the rule that a lone session does not rotate. Eight dots, the `SL_MAX_SESSIONS` cap, span 54px and still leave the corner free for the pin marker. The dots do not shift when the marker appears, because a row that moved sideways on a pin would read as the position having changed.

The state row (`working`, `needs you`) was removed to give the label the bottom two thirds of the panel. The state is already on the lamps, in colour, from across the room — spelling it out in text was the worst-value row of the three.

### Rotation

More than one session cycles the screen, **at least** three seconds each, in the order the relay sent (which is start time order). A session keeps its slot as others come and go, because slots are matched by `id` rather than by position.

One session does not rotate. A cycle of one is a static screen redrawing for nothing.

**Rotation waits for scrolling.** Three seconds is a minimum, not a period. A slot advances only when the interval has passed *and* the label has finished its scroll cycle, so rotation is paced by content and runs slightly irregularly on purpose. A label long enough to take seventeen seconds to scroll holds the screen for seventeen seconds.

When a session turns red the screen jumps to it immediately and holds a full interval before resuming.

### Scrolling

The 10×20 label font puts 7 characters on a line. Labels that fit are drawn statically and never move. Longer labels run a marquee: hold at the start for a second, scroll left at one pixel per 68ms, hold at the end, reset.

It is a marquee and not a wrap-around loop because a loop never gives a stable moment to read the first characters, which is where the useful part of a branch name usually is.

Scroll position resets whenever the session changes colour.

### Button

| Press | Duration | Action |
|---|---|---|
| Short | under 500ms | Pin or unpin the session on screen |
| Long | 500ms or more | Advance to the next session, reset scroll |

Debounced over 50ms. A long press fires while the button is still held rather than on release, so a deliberate hold feels responsive.

A pin expires two ways: when its session disappears from a frame, and after **15 minutes** regardless. Without expiry you pin something, forget, and quietly stop seeing every other session.

**A pin never affects the lamps.** See below.

### Lamps

Exactly one lamp is lit at a time, matching the aggregate `color`. `off` means all three dark, which is what "nothing is running" looks like — green means finished.

The LEDs are driven by PWM at a duty of 80/255 rather than at full current. Behind a printed diffuser this looks the same to the eye, and the LEDs dominate the battery budget, so it is the single biggest lever on run time. Change `LAMP_DUTY` in `lamps.h` if your diffuser is thicker.

#### The LEDC API split is unverified — read this before you flash

`lamps.cpp` contains two implementations behind `#if ESP_ARDUINO_VERSION_MAJOR >= 3`, because the ESP32 Arduino core renamed the LEDC API in 3.0.

| Core | API | What `lamps.cpp` calls |
|---|---|---|
| 3.x | pin-based | `ledcAttach(pin, freq, bits)`, then `ledcWrite(pin, duty)` |
| 2.x | channel-based | `ledcSetup(ch, freq, bits)` and `ledcAttachPin(pin, ch)`, then `ledcWrite(ch, duty)` |

**Targeted core: 3.x.** `make setup` installs the current `esp32:esp32`, which is 3.x, and that is the branch this firmware was written against.

**Neither branch has been compiled for an ESP32, and only one of them ever will be on any given machine.** The host stub declares `ESP_ARDUINO_VERSION_MAJOR 3`, so the host build exercises the 3.x branch only, and the stub's `ledcAttach` and `ledcWrite` do nothing but record a duty into an array. That means:

- The host tests prove the lamp *logic* — one LED lit at a time, `off` clearing all three, `set()` being idempotent. They prove nothing about the LEDC calls themselves.
- The 2.x branch is compiled by nothing, anywhere. It is unreachable on a 3.x core and untested on a 2.x one. Treat it as a best-effort fallback that has never been run.
- Signatures, argument order and return types on both branches were written from the core's documented API, not verified against a compiler.

If the LEDs stay dark on a board that is otherwise working, this split is the first place to look. Check which core version is installed with `arduino-cli core list` (Arduino IDE: Tools -> Board -> Boards Manager, search `esp32`), and confirm the matching branch is the one being compiled.

#### The lamps and the display stay apart

`lamps.h` and `lamps.cpp` contain no reference to `Display`, and `display.h` and `display.cpp` contain no reference to `Lamps`. That separation is what makes "a pinned or rotating screen can never hide a red lamp" a structural property rather than a promise. See [How the pin is kept away from the lamps](#how-the-pin-is-kept-away-from-the-lamps).

### Bluetooth

The device serves BLE and USB serial at the same time, from one image. Which link the relay uses is the relay's choice: `--ble` selects the radio, and with no flag it looks for a serial light first and a Bluetooth one second. A build flag would make a decision at flash time about something discovered at run time.

| | |
|---|---|
| Service | `6e5d0001-b5a3-f393-e0a9-e50e24dcca9e`, advertised |
| Characteristic | `6e5d0002-b5a3-f393-e0a9-e50e24dcca9e`, write only |
| Advertised name | `stoplight`, for humans only |

**The central matches on the service UUID and nothing else.** A board that fails to advertise it is invisible however it is named, so `addServiceUUID` is the one line that makes the light findable at all.

**`blelink.cpp` does not parse.** A chunk arrives, its bytes go into a queue, and `loop()` drains that queue into the same `LineReader` the cable uses. The contract says a BLE chunk is indistinguishable from a partial serial read, and feeding both into one reader is what makes that true in code rather than only on paper. Two readers would be two chances to disagree about the frame format, and the BLE one would be the one nobody watches.

The queue is also the thread handoff. The write callback runs on the Bluetooth stack's task rather than the Arduino loop task, and parsing there would touch `Display` and `Lamps` from a second thread when neither is synchronised.

**A chunk that does not fit is dropped whole.** A partial write leaves a hole in the middle of a frame, which costs that frame anyway and can consume the next frame's newline as well, so dropping one chunk is strictly cheaper than truncating one.

**Advertising restarts on disconnect.** It stops on connect and does not resume by itself, so without that line the light is invisible after the first central ever disconnects and only a power cycle cures it.

The wire contract both ends implement is `ble.ChunkContract` in `internal/transport/ble/contract.go`. It is a Go constant rather than a comment so neither end can change it silently.

**The radio costs flash.** The image roughly doubles, from 26% to 51% of program storage, and RAM goes from 5% to 7%. Comfortable on a 4MB part, and worth knowing before choosing a partition scheme.

## How the pin is kept away from the lamps

The guarantee, from [design.md](../design.md): *a pinned or rotating screen can never hide a red lamp*. The device's whole value is that a green glance is trustworthy, so this is enforced by structure rather than by care.

- `lamps.h` has no reference to `Display`, and `display.h` has no reference to `Lamps`. Neither module can call the other.
- The only way to change a lamp is `Lamps::set(Color)`, and the only caller is one statement in `loop()`, which passes the aggregate straight from the parsed frame.
- Rotation index, scroll position and pin state live entirely inside `Display` and are never read when setting the lamps.

To break the invariant you would have to add a `Lamps` include and a call inside the display module. That is a conspicuous change in review, not an easy mistake.

## Parsing

The parser is hand written. **This is deliberate, and the alternative was ArduinoJson.**

The frame is a flat object with two keys, one of which is an array of flat objects with four string keys. There is no deep nesting, no numbers to convert, and nothing to re-serialise. A scanner for that shape is about 200 lines, and against a dependency it buys:

- **No allocator.** Every buffer is fixed size and lives in the object, so there is no heap fragmentation over a multi-day uptime and no `JsonDocument` capacity to guess at. An oversized label truncates instead of failing.
- **Explicit forward compatibility.** Unknown keys are skipped at any depth by a `skipValue` that steps over whole objects and arrays. Adding a field to the relay cannot break a light flashed today.
- **Partial frames still count.** A truncated line still applies whatever parsed before the break. Dropping a frame because a field the firmware never reads was malformed could mean dropping a red lamp.
- **Auditable.** The failure modes of the one component that touches untrusted input can be read end to end.

Guards, all exercised by the host tests: labels over 48 characters truncate; nesting deeper than 16 is refused; sessions past the eighth are skipped while the rest of the frame still parses; a session with no `id` is dropped, since it cannot be tracked across frames or pinned; a session whose `id` is already present is dropped for the same reason; non-ASCII collapses to a single `?` because the font has no glyph for it.

**A refused value costs one key, not the frame.** When `skipValue` gives up — nesting past the guard, or a malformed value — the parser scans forward to the next top-level comma and carries on, rather than abandoning every later key. It used to abandon them, which meant a frame like `{"x":[[[ …1000 deep… ]]],"color":"red"}` dropped the aggregate and the red lamp with it, over a field the firmware does not even read. The forward scan is string-aware, so a comma or brace inside a string literal is not mistaken for structure.

**Duplicate ids are dropped, keeping the first.** Ids are the key for the pin and for preserving a rotation slot, and both take the first match, so a second session sharing an id got a slot that nothing could ever address: a pin on it silently anchored to the first instead, and the did-this-turn-red check read the first's colour. This is the same failure `SL_MAX_ID` fixed, arriving from the relay rather than from truncation.

### Key order: `color` first, and why it is asserted on both sides

The parser itself is order-independent, and so is the oversized-line salvage. But the two salvage paths are not equally strong, and which one applies is decided purely by where `color` sits in the frame.

| `color` position | Recovered from | Strength |
|---|---|---|
| First | The prefix the reader kept, by a plain forward parse | Exact, however far past the cap the line ran |
| Last | The last `SL_TAIL_MAX` (96) bytes, retained in a ring buffer | Works, but the key and its value must fall inside that window |

Both light the right lamp, which is the point: **a truncated frame must never lose its aggregate because of where a Go struct happened to declare a field.** The salvage used to be prefix-only, so `{"sessions":[…huge…],"color":"red"}` recovered nothing and the lamps held a stale green — a red light silently disappearing because of field ordering in code on another machine.

The relay emits `color` first because `Frame` in `internal/stoplight/frame.go` declares it first, and `TestFrameSerialisesColorFirst` in that package asserts it on the wire bytes. Reordering the struct now fails a Go test with an explanatory message instead of quietly downgrading every oversized frame to the weaker path. The contract is written out in `firmware/stoplight/protocol.h` under "KEY ORDER".

The tail scan only accepts a `"color":"<name>"` pair followed by the frame's closing brace and nothing else. A `color` still inside the sessions array belongs to one session and is refused, so a per-session colour can never reach the lamps by this route.

### Sizing, and why a dropped line was a wrong colour

`SL_LINE_MAX` is 1536 bytes. It has to exceed the largest frame the relay can send, because a line over the cap is not merely truncated — it stops being usable as a session list at all.

The worst case is the eight-session cap at the maximum id and label length, which measures 1199 bytes: 8 entries of 145 bytes, 7 separating commas, and a 32-byte envelope. 1536 leaves 337 bytes of headroom for a label override longer than `SL_MAX_LABEL` and for any small key a future relay adds.

The earlier value of 512 was too small for real use, and the way it failed was the worst kind. Five sessions with 36-character UUIDs produce a 543-byte frame, so the line was discarded whole — the aggregate colour with it. Because frames are sent only on change, every later frame was oversized too, and the lamps held their last colour indefinitely. A session going red never showed.

Two changes make that unreachable, and a third contains the damage if it somehow happens anyway:

- The relay caps the list at eight entries (`MaxFrameSessions` in `internal/stoplight/tracker.go`) while still computing the aggregate over **every** live session. A ninth session going red still turns the lamp red even though it cannot be named on screen.
- `SL_LINE_MAX` is sized against the real worst case rather than a guess.
- **An oversized line now degrades instead of vanishing.** The reader scans the prefix it did keep for the top-level `color` key, and if that fails it scans a retained tail, so the aggregate reaches the lamps whichever end of the frame the key sits at. The screen is left untouched either way. Losing the labels is acceptable; losing the lamp is not. A `color` inside the sessions array is never mistaken for the aggregate, and when the aggregate genuinely cannot be recovered the lamps are left alone rather than guessed at. See [Key order](#key-order-color-first-and-why-it-is-asserted-on-both-sides).

`SL_MAX_ID` is 40, not 24. A Claude Code `session_id` is a 36-character UUID, and ids are compared with `strcmp`, so a truncated id is not a shorter id — it is a **wrong** id. At 24 characters two sessions sharing a UUID prefix collapsed into one, which made the pin follow the wrong session and made the did-this-turn-red check read another session's previous colour, suppressing the jump to red. Both caps together cost 1296 bytes of static RAM (2060 to 3356 across `Frame`, `LineReader` and `Display`), which is 0.8% of the C3's 400KB.

## Modules

| File | Owns |
|---|---|
| `stoplight/stoplight.ino` | Setup, the non-blocking main loop, wiring the modules together |
| `stoplight/protocol.{h,cpp}` | Frame struct, JSON parser, serial line reader |
| `stoplight/display.{h,cpp}` | Screen, rotation, marquee scrolling, pin state |
| `stoplight/lamps.{h,cpp}` | Three LEDs, PWM dimming |
| `stoplight/blelink.{h,cpp}` | The GATT peripheral and the byte queue. No parsing: see [Bluetooth](#bluetooth) |
| `stoplight/button.{h,cpp}` | Debounce, short and long press |

Nothing blocks. There is no `delay()` in `loop()`; every timer is a `millis()` comparison, because a blocking wait would stall serial reads and make the button feel dead. All elapsed-time maths uses unsigned subtraction, so it stays correct across the `millis()` rollover at about 49 days.

Serial reads are capped at 256 bytes per iteration so a fast writer cannot starve the button and the display. The reader keeps its partial line between iterations, so stopping early costs nothing.

Power: the screen blanks after five minutes with no frame and wakes on the next one. **The lamps stay lit** — the colour is still true, and it is the reason the device exists.

## Troubleshooting

### The screen is completely blank

**No host test can catch this, and the symptom is a screen that looks BROKEN rather than misconfigured.** That combination is why it is worth reading the list below before reaching for a multimeter.

The 72×40 offset lives entirely inside the U8g2 constructor. The host stub replaces that constructor with one that records nothing about geometry, and there are no pixels on a host to inspect, so the whole test suite passes identically with the right constructor and the wrong one. The 440 checks say nothing at all about this. It is the single largest gap between "the tests pass" and "the device works".

And when it is wrong there is no partial output to hint at it: no flicker, no clipped text, no garbled row. Every pixel lands outside the visible window, so the panel is **indistinguishable from a dead screen, an unpowered screen, a wrong I²C address, or a broken solder joint**. People replace the board over this. Rule the constructor out first, because it costs one line to check and it is the most likely cause by a wide margin.

In order of likelihood:

1. **Wrong constructor.** By far the most common cause, and the one no test can find for you. It must be `U8G2_SSD1306_72X40_ER_F_HW_I2C`. A generic `128X64_NONAME` driver renders outside the visible window and the panel looks dead — not wrong, *dead*. See the top of this file.
2. **Wrong I²C address.** This board is normally `0x3C`, but some units ship as `0x3D`. Change `OLED_ADDR` in `stoplight.ino`, or scan for it:

   ```cpp
   #include <Wire.h>
   void setup() {
     Serial.begin(115200);
     Wire.begin(5, 6);            // this board's SDA, SCL
     for (uint8_t a = 1; a < 127; a++) {
       Wire.beginTransmission(a);
       if (Wire.endTransmission() == 0) Serial.printf("found 0x%02X\n", a);
     }
   }
   void loop() {}
   ```

   No address at all means a hardware fault rather than a firmware one.
3. **Wrong I²C pins.** `Wire.begin(5, 6)` must run before `u8g2.begin()`. The core's defaults are not this board's pins.
4. **The panel is asleep.** After five minutes with no frame the screen blanks by design. Send any frame to wake it.

### Nothing happens when I paste JSON

- Set the serial monitor line ending to **Newline**. The parser acts on the newline, so without one the frame is never complete. `make monitor` already does this.
- Confirm the baud rate is **115200**.
- Confirm **USB CDC On Boot** is Enabled. Without it `Serial` goes to the UART pins, not USB. `make flash` sets it; a GUI flash may not have.
- Confirm the JSON is on one line. A pretty-printed frame spanning several lines parses as several broken frames.

### The board does not appear as a serial port

- Use a **data** USB-C cable. Charge-only cables enumerate nothing, and they look identical. This is the usual cause.
- Force download mode: hold `BOOT`, tap `RESET`, release `BOOT`, then upload.
- On macOS the port is `/dev/cu.usbmodem*`. `make ports` lists what arduino-cli can see.

### An LED never lights

- Check polarity. The long leg (anode) goes to the resistor and the GPIO pin; the short leg to ground. Backwards, it stays dark.
- Confirm the 220Ω resistor is in the anode line and all cathodes share the ground rail.
- The LEDs run dimmed at `LAMP_DUTY` 80/255, which is noticeably less than full brightness and is not a fault. Raise it in `lamps.h` to rule dimming in or out.

### The button does nothing, or triggers on its own

- It goes between GPIO 3 and **ground**, with no external resistor. The firmware enables the internal pull-up.
- A floating pin reads as random presses, which means the ground leg is not actually connected.

### Rotation looks irregular

That is correct. Rotation waits for scrolling, so slots with long labels hold the screen for longer than three seconds. A pinned session does not rotate at all — look for the `*` marker.

## Verified on hardware

**2026-09-06. The firmware compiles for the ESP32-C3 and runs on the real board.** Everything in this section was observed on the glass, not inferred from a passing test.

| Proven | Detail |
|---|---|
| The build | 346434 bytes of flash (26% of 1310720) and 19372 bytes of RAM (5% of 327680), at the FQBN in the Makefile |
| I²C | The panel answers at `0x3C` on SDA=GPIO5 and SCL=GPIO6, found by a scan |
| The constructor | `U8G2_SSD1306_72X40_ER_F_HW_I2C` is right, and the measured `x_offset` is 28. Text lands inside the visible window. |
| Frame delivery | A plain write to the device node is enough. **No DTR or RTS handshake is needed** — `printf '{…}\n' > /dev/cu.usbmodem*` renders a frame. |
| The relay | The Go relay drives the panel end to end over `--serial`, from an HTTP POST to pixels |
| Rotation | Several sessions cycle on screen, with the filled position dot tracking the label |
| Scrolling | A label longer than the line marquees: hold, scroll left, hold, reset |
| Rotation pacing | A long label holds the screen visibly longer than a short one, so rotation really is paced by content rather than by a clock |
| The off state | Ending every session clears the screen rather than freezing the last frame |

**2026-09-10. The lamps work, and the invariant holds on real hardware.** The LEDs are wired to GPIO 0, 1 and 2 and were driven from the relay over serial.

| Proven | Detail |
|---|---|
| The three LEDs light | Yellow and red both observed. The LEDs are wired and the lamp path runs end to end. |
| **The LEDC API split** | The 3.x branch of `lamps.cpp` works on real silicon. It had never been compiled for an ESP32 by anything before this — the host stub only records a duty into an array. The 2.x branch remains compiled by nothing. |
| PWM dimming at `LAMP_DUTY` | 80/255 is visible and readable on a bare LED, no diffuser |
| **The lamp stays red while the screen shows a green session** | The invariant the whole device rests on. A frame with aggregate `red` and three sessions coloured red, yellow and green held the lamp red through all three labels, including while the screen showed the green one. The lamp follows the aggregate and never the session on screen. |
| Rotation on hardware | Three sessions cycle every three seconds with the filled position dot tracking the label |

The no-handshake result is worth keeping. It is the reason `internal/transport/serial` can open the port with a plain `os.OpenFile` and stay on the standard library, and it was confirmed by writing a frame from a bare shell.

**2026-09-11. The radio works, and the same image serves both links.** The relay drove the board over BLE with the USB cable supplying power only.

| Proven | Detail |
|---|---|
| The light is findable | The relay matched it by service UUID alone, with no name, and connected |
| Frames cross the radio | Red, yellow and green each confirmed by eye over BLE, one lamp at a time |
| Reassembly | No send errors across the session: every chunked frame arrived whole and parsed |
| Advertising resumes | A disconnect restarts advertising, so a second connection needs no power cycle |
| Both links, one image | The radio starts alongside serial rather than instead of it, so the transport is the relay's choice at run time |

The same three lamps were confirmed over USB serial immediately beforehand, which is what makes the comparison worth anything: the difference between the two runs was the transport and nothing else.

**The radio costs flash, not correctness.** The image went from 350424 bytes (26%) to 680543 bytes (51%) of program storage, and RAM from 19372 (5%) to 25872 (7%). That is comfortable on a 4MB part and worth knowing before choosing a partition scheme.

**The USB port name changes when the radio is enabled.** The board enumerated as `/dev/cu.usbmodem1101` before and `/dev/cu.usbmodem101` after. Nothing is wrong; `make ports` lists what is actually there, and `PORT=` overrides the guess.

### Still unverified: everything that needs parts not yet attached

These are not doubts about the code. Nothing is wired to them yet, so nobody has looked.

| Unverified | Needs |
|---|---|
| The button: short press pins, long press advances | A button on GPIO 3 |
| Battery life | A battery |
| Enclosure fit | A printed enclosure |

### Host tests

What was verified on a host compiler with U8g2 and the Arduino API stubbed out. Run it yourself with `cd firmware && make test`; see [Host tests](#host-tests).

- All four modules and the sketch compile clean under `-Wall -Wextra -Wconversion -Wshadow`, with no warnings.
- **440 behavioural checks pass** under AddressSanitizer and UndefinedBehaviorSanitizer.
- Those checks include: frames at 1, 4, 5 and 8 sessions all fitting the line buffer, an oversized frame surrendering its aggregate colour with `color` at either end of the frame, 36-character UUIDs staying distinct, duplicate ids never taking two slots, a value too deeply nested to skip costing one key rather than the aggregate behind it, rotation genuinely waiting for a long label to finish scrolling, the immediate jump on red, a red hold whose deadline lands on exactly 0 still being honoured, the pin stopping rotation and expiring both ways, a session keeping its slot as others leave, truncated and deeply nested input, a `\uXXXX` escape cut off at the end of a heap-exact buffer reading nothing past the terminator, and short/long press classification across the `millis()` rollover.
- The U8g2 constructor, method signatures and font name were checked against the library source rather than recalled.

### What the host tests cannot reach

The stubs are a model of the Arduino API, not the API itself. They cannot catch a linker error against the real core, a timing problem, an I²C fault, or anything about actual pixels. Four gaps are worth naming, because in each one a passing test suite means nothing at all:

| Gap | Why no test reaches it | What a failure looks like |
|---|---|---|
| **The 72×40 panel offset** | It lives inside the U8g2 constructor, which the stub replaces. There are no pixels on a host to inspect, so every check passes identically with the wrong constructor. | A screen that looks **dead**, not misconfigured — no flicker, no clipped text. Indistinguishable from a hardware fault. See [The screen is completely blank](#the-screen-is-completely-blank). *Closed on 2026-09-06: the panel renders.* |
| **The LEDC API split in `lamps.cpp`** | The stub declares core 3.x, so only that branch is compiled, and its `ledcAttach`/`ledcWrite` do nothing but record a duty. The 2.x branch is compiled by nothing, anywhere. | LEDs that never light on an otherwise working board. See [the LEDC note](#the-ledc-api-split-is-unverified--read-this-before-you-flash). *Closed on 2026-09-10 for the 3.x branch: all three lamps light. The 2.x branch remains compiled by nothing.* |
| **The radio itself** | `BleLink::begin()` is a no-op under `SL_HOST_TEST`, because there is no BLE stack on a host. The queue, the drop rule and the reassembly are plain C++ and are tested; advertising, the UUIDs and MTU negotiation are not. | A light nothing can find, or one that connects and never receives a frame. *Closed on 2026-09-11: the relay matched it by UUID and drove all three lamps over the radio.* |
| **Anything about real I²C, timing or the USB CDC port** | The stubs have no transport and no clock; the test sets time directly. | A blank screen, an empty serial monitor, or a marquee at the wrong speed. *Closed on 2026-09-06 for I²C, the CDC port and the marquee.* |

None of that substitutes for the panel lighting up. Check first that the screen renders at all, then that the marquee is readable at `DISP_SCROLL_STEP_MS`, and then that the LED brightness suits your diffuser.

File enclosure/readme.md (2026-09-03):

# Enclosure

The case for [Stoplight](../readme.md). Four printed parts, about **36 × 78 × 18mm**, roughly a matchbox standing upright.

```
          FRONT                       SIDE (cut away)
                                    visor    body
         ╭───────╮                  ├──┤  ├───────┤
     ┌───┤  ( )  ├───┐          ┌───────────────────┐   0mm
     │   ╰───────╯   │          │ ╲     │  button   │
     │    recessed   │          │       ├───────────┤   8mm
     ├───────────────┤          │  ╲    │           │
     │               │          │   ╲___│▓  ┌─────┐ │
     │     ╭─────╮   │          │   ╱▒▒▒│▓  │ ███ │ │
     │     │  ●  │ R │          │  ╱────┤▓  │ ███ │ │  battery
     │     ╰─────╯   │          │       │   │ ███ │ │  stands
     │     ╭─────╮   │          │   ╲___│▓  │ ███ │ │  upright
     │     │  ●  │ Y │          │   ╱▒▒▒│▓  │ ███ │ │  behind
     │     ╰─────╯   │          │  ╱────┤▓  │ ███ │ │  the lamps
     │     ╭─────╮   │          │       │   └─────┘ │
     │     │  ●  │ G │          │   ╲___│▓          │
     │     ╰─────╯   │          │   ╱▒▒▒│▓          │
     │               │          │  ╱────┤           │  52mm
     ├───────────────┤          ├───────────────────┤
     │  ┌─────────┐  │          │       │┌──┐ ┌───┐ │
     │  │ ▪ 2/4   │  │          │       ││▉▉│ │TP4│ │  board and
     │  │ auth-api│  │          │       ││▉▉│ └───┘ │  charger
     │  │ ● needs │  │          │       │└──┘       │
     │  └─────────┘  │          │        ╧          │
     └───────┬───────┘          └───────────────────┘  78mm
             ╧                    ├─── 25mm total ──┤
           USB-C
     ├──── 36mm ────┤            ▒ lens   ▓ LED   ╲╱ visor
```

Three things earn their place in that shape.

The **battery stands upright behind the lamp column**, in space the lamps do not use. Lay it flat underneath instead and the device grows to 184mm, or sprawls to 70mm deep. This is what keeps it the size of a matchbox.

The **visors** hood each lamp and are open underneath, so a lamp is shaded from the ceiling and your monitor but still bright from where you sit. This is the detail that makes the thing read as a traffic light rather than three LEDs in a box.

The **button is recessed** into a dish on the top face. Your finger finds it without looking, and nothing knocks it by accident.

## Files

| File | What it is |
|---|---|
| **`params.json`** | **Every dimension. The only file you edit.** |
| `params.py` | Loads the JSON, computes derived values, writes the `.scad` block |
| `stoplight.scad` | OpenSCAD geometry. Its parameter block is generated. |
| `gen_stl.py` | Writes the STLs. Standard library only. |
| `gen_docs.py` | Regenerates the tables in this file |
| `stl/*.stl` | Ready to slice. |

One dimension lives in one place. Change the button size in `params.json` and the OpenSCAD source, the STL generator and the tables below all follow:

```bash
python3 params.py     # rewrites the parameter block in stoplight.scad
python3 gen_stl.py    # rewrites stl/*.stl
python3 gen_docs.py   # rewrites the tables in this readme
```

Two paths to a printable file, because they suit different moments.

Run `python3 gen_stl.py` and slice what lands in `stl/`. Nothing to install, and it takes under a second.

Or open `stoplight.scad` in [OpenSCAD](https://openscad.org) and export from there. The geometry is exact rather than voxelised, which matters for the curved surfaces. Use this once you have measured your own parts.

Both read the same numbers, so they cannot drift.

## The four parts

```
              ◓             1 × PLUNGER
              │               drops through the top face
              ▼               into the dish

        ╭───────────╮
        │     ◌     │       1 × BODY
   ◍ ───┤   ╭───╮   │         everything else is
        │   ╰───╯   │         a hole in this
   ◍ ───┤   ╭───╮   │
        │   ╰───╯   │       3 × LENS
   ◍ ───┤   ╭───╮   │         translucent, sparse
        │   ╰───╯   │         press straight in
        │ ┌───────┐ │
        │ │screen │ │
        │ └───────┘ │
        ╰───────────╯
              ▲
        ┌─────┴─────┐       1 × BACK COVER
        │ ▪▪▪   ▪▪▪ │         4 screws, one vent
        │  ═══════  │         closes the whole thing
        └───────────┘
```

| Part | Qty | Filament | Settings | Time |
|---|---|---|---|---|
| `body` | 1 | Matte black | 0.2mm layers, 5 perimeters, 20% infill | A few hours |
| `lens` | 3 | Translucent or natural | 15% infill, 2 perimeters, **no top or bottom layers** | Two minutes each |
| `back` | 1 | Matte black | 0.2mm layers, 20% infill | Under an hour |
| `plunger` | 1 | Matte black | 0.15mm layers for a smoother slide | Two minutes |

The lens setting is the one that matters. Sparse infill with open ends is what diffuses the LED into an even glow. Print a lens solid and you get a bright dot with a dark ring around it.

Print the body with the open back face down on the plate. No supports needed: the lamp bores are horizontal cylinders under 10mm, which bridge cleanly, and the screen window is small enough to span.

Print a lens and the plunger first. They cost you four minutes and they tell you whether your printer's tolerances match the model, which is worth knowing before you commit hours to the body.

## Component sizes

Every dimension derives from these. Measure your own parts, because module sizes vary between suppliers.

<!-- generated from params.json — run gen_docs.py components -->

| Component | L × W × H | Notes |
|---|---|---|
| ESP32-C3 SuperMini | 25.0 × 20.5 × 6.0mm | Screen on board. Lit area only 9.2 × 5.2mm. |
| LiPo 500mAh, 503035 | 35.0 × 30.0 × 5.0mm | Widest part. Sets internal width. |
| TP4057 module | 26.0 × 17.0 × 4.0mm | Mounts behind the battery |
| 5mm LED | 5.0mm diameter | Body about 8mm long with the flange |

The battery is widest at 30mm, so it sets the internal width. Nothing is longer than 35mm, which is why the device is short.

<!-- end generated -->

## Key dimensions

<!-- generated from params.json — run gen_docs.py dimensions -->

| Dimension | Value |
|---|---|
| Overall | 36 × 78 × 18mm |
| Wall thickness | 2.0mm, 3.0mm on top |
| Lamp bores | 10.0mm ⌀, 12.0mm deep, 12.5mm apart |
| Lamp centres | z = 60.5, 48.0, 35.5mm from the base |
| Lens inserts | 10.0mm ⌀ × 5.0mm |
| Visors | 7.0mm projection, 1.6mm wall |
| Button pocket | 6.0mm switch, 9.0mm dish 1.2mm deep |
| Screen window | 12.0 × 10.0mm |
| Board rails | 1.6mm thick, 4.0mm reach |
| Print clearance | fit = 0.2mm between mating parts |

<!-- end generated -->

These tables are generated. To change any of them, edit `params.json` and run `python3 params.py && python3 gen_docs.py`.

## Body

Matte black PLA, 2.0mm walls, which is five perimeters at a 0.4mm nozzle. Described from the top down, which is the order it prints in.

The **button** occupies the top 8mm. A 6 × 6mm tactile switch sits in a 7 × 7mm pocket below the top face, with a 4mm hole through the face for the plunger and a 9mm dish around it so the cap finishes below the surface. Keep the top face at 3mm rather than 2mm and add a short internal rib beside the pocket, because pressing down puts a load through the whole body and a 2mm top flexes enough to make the press feel soft.

The top is the right face for the button. You press straight down, which the desk resists, so the case does not rock or slide the way a side press would. It is also the face you can find without looking, which matters for something you operate while reading something else.

The **lamp column** is three bores, 10mm diameter, 12mm deep, spaced 12.5mm centre to centre. Behind each, a 5.2mm hole passes through for the LED. Keep the wall between adjacent bores solid, because that wall is what stops red bleeding into yellow. Each bore carries a visor: a hood projecting 7mm from the front face, open underneath.

The **battery bay** sits behind the lamp column, 32 × 37 × 6mm, open to the back. The charging module sits below it against the back wall, USB-C port facing down through a 10 × 6mm opening in the base.

The **board** goes in the lower front section, screen facing forward, with a 12 × 10mm window over the screen and an opening in the base for its USB-C port so you can reflash without opening the case.

It is held by printed rails rather than screws. The board slides down between two 1.6mm side rails onto a ledge, four tabs catch its front face, and a stop above it means the board cannot lift once the cover is on. Nothing to fasten, nothing to lose, and it comes out again if you need it.

## Lens inserts

Three 10mm discs, 5mm thick, with a 5.2mm blind socket in the back for the LED.

Print at 15% infill, two perimeters, no top or bottom solid layers if your slicer allows it. The sparse infill is doing the diffusing. A solid lens looks like a bright dot; a sparse one glows evenly across the whole face, and that difference is the single biggest visual upgrade in the build.

Press fit is intended. Size the discs 0.2mm under the bore and they stay put without glue.

## Back cover

Flat, and small enough that four M2 screws into printed bosses are enough. Heat-set inserts are cleaner if you have them, but at this size the cover is under no load.

It carries a 2mm vent slot near the charging module. A LiPo charging in a sealed box is a bad habit even at these currents.

## Fit

`fit = 0.20` in both files is the gap between mating parts. Printers vary, so the first set is a test.

If the lens inserts fall out, lower it to 0.15. If they will not seat, raise it to 0.25. The same variable governs the plunger, which should drop in and move freely without rattling.

If red bleeds into yellow, thicken the divider walls to 3mm.

## Before you print

Measure your own components and edit `params.json`. The defaults are nominal figures from supplier listings, and two are most likely to differ.

**The button.** `components.btn_body` assumes a 6 × 6mm tactile switch. A panel-mount button is often 12mm across and needs 10mm behind the face, which changes the pocket, the top thickness and the overall height.

**The LEDs.** `components.led_hole` fits a bare 5mm LED. Many have a flange at the base about 5.8mm across, which needs a wider hole or a shallow counterbore.

Also check the battery. `503035` cells vary by about a millimetre between suppliers, and the bay has 1mm of slack on each side, set by `print.slack`.

After any edit:

```bash
python3 params.py && python3 gen_stl.py && python3 gen_docs.py
```

Print the enclosure last. It should follow parts you are holding rather than numbers from a product page.

## Known limits

`gen_stl.py` meshes on a 0.5mm voxel grid, so curved surfaces are faceted at that scale and the files are larger than they need to be. It is fine for printing at 0.2mm layers, where the slicer smooths most of it away, but the OpenSCAD output is cleaner if you care about the finish on the lens bores.

The STL geometry has been verified by point probes rather than by a slicer. Open the files in your slicer before committing to a long print, and check that it does not report non-manifold edges.

Neither file models the wiring. Leave room for three LED leads, two button wires and the battery cable when you assemble, and route them down the back of the cavity where the cover closes over them.

## License

[Apache License 2.0](../LICENSE), the same as the rest of Stoplight. Copyright 2026 Cidekar, LLC.

Print them, remix them, sell the prints. Keep the notice and say what you changed.

If you improve the models, [`CONTRIBUTING.md`](../CONTRIBUTING.md) explains how to send them back. Fit tolerances from other printers are especially welcome.

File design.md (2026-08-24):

# Design

How Stoplight is built. Four layers, each derived from the one above it: the state machine defines behaviour, the types encode it, the packages arrange it, and the wire protocol carries it.

The public contract is [RFC 1](rfc.md), which any agent can implement. This document is the implementation behind it. Where the two overlap, the RFC wins.

Read the [readme](readme.md) first for what the device does and why.

## Contents

- [State machine](#state-machine)
- [Go types](#go-types)
- [Package layout](#package-layout)
- [Wire protocol](#wire-protocol)
- [Invariants](#invariants)

---

## State machine

### Session states

A session is one unit of work a human is waiting on: a conversation with an agent, a build, a test run. Every session is in exactly one state.

| State | Colour | Meaning |
|---|---|---|
| `Idle` | green | Started, nothing happening |
| `Working` | yellow | The producer is doing work on its own |
| `Blocked` | red | The producer needs a human before it can continue |
| `Done` | green | Finished the last turn |
| `Expired` | — | Went quiet, dropped from the set |

`Idle` and `Done` are both green but stay distinct, because the screen shows different text and only `Done` implies work completed.

### Events

Five arrive from producers, as defined in [RFC 1 §3](rfc.md#3-events). One is internal.

| Event | Source |
|---|---|
| `idle` | producer |
| `started` | producer |
| `blocked` | producer |
| `finished` | producer |
| `ended` | producer |
| `Timeout` | relay, after silence |

These names are deliberately semantic rather than borrowed from any agent's vocabulary. Claude Code's hook names are translated at the adapter boundary and appear nowhere below it.

### Transitions

```
                      idle
                       │
                       ▼
                   ┌───────┐
                   │ Idle  │◀────────────┐
                   └───┬───┘             │
                       │ started         │
                       ▼                 │
                   ┌─────────┐           │
             ┌────▶│ Working │────┐      │ idle
             │     └────┬────┘    │      │ (restart)
             │          │         │      │
             │ started  │ blocked │ finished
             │          ▼         ▼      │
             │     ┌─────────┐ ┌──────┐  │
             └─────┤ Blocked │ │ Done ├──┘
                   └────┬────┘ └───┬──┘
                        │          │
               Timeout  │          │ Timeout
               or ended ▼          ▼ or ended
                   ┌──────────────────┐
                   │     Expired      │
                   └──────────────────┘
                     terminal, and
                     dropped from set

    Four edges are left out to keep the diagram readable. Idle
    takes blocked to Blocked and finished to Done. Blocked takes
    finished to Done, and Done takes blocked to Blocked. The
    table below is complete; the diagram is not.

    Expired has no edge out. The `idle` restart applies from any
    LIVE state, not from Expired: a session that expired is
    deleted, and a later report for that ID starts a new one.
```

The two edges between `Blocked` and `Done` are the ones most easily missed, and both are ordinary. `finished` goes from `Blocked` to `Done`: the human answered and the agent completed the turn. `blocked` goes from `Done` to `Blocked`: a finished session began a new turn and hit a prompt inside it.

Written out, because the diagram compresses:

| From | Event | To |
|---|---|---|
| `Idle` | `started` | `Working` |
| `Idle` | `blocked` | `Blocked` |
| `Idle` | `finished` | `Done` |
| `Working` | `blocked` | `Blocked` |
| `Working` | `finished` | `Done` |
| `Blocked` | `started` | `Working` |
| `Blocked` | `finished` | `Done` |
| `Done` | `started` | `Working` |
| `Done` | `blocked` | `Blocked` |
| any live | `Timeout` | `Expired` |
| any live | `ended` | `Expired` |
| any live | `idle` | `Idle` (restart) |
| `Expired` | anything | `Expired` (terminal) |

`started`, `blocked` and `finished` all apply from every live state. The event says what the agent is doing now, and that is true whatever it was doing before. Restricting any of them by source state only drops a light the producer asked for.

The remaining no-ops are the pairs where the session is already in the state the event names, and every pair out of `Expired`. Repeating an event is a keepalive: a `finished` while already `Done` changes nothing, and that is normal rather than an error.

`Expired` is terminal, matching [RFC 1 §7](rfc.md#7-session-lifecycle), where the diagram ends there with no arrow out. Nothing revives an expired session in place. `idle` used to, on the reasoning that a restarting producer should get its session back, but that row was unreachable: the tracker DELETES an expired session the moment it is marked, so no event ever arrives at one. A restarting producer already takes the path the RFC intends. Its session is gone, and its next report creates a fresh one through `InitialState` with a new `Started`, which puts it at the end of the rotation where a just-started session belongs. Reviving in place would have kept the original `Started` and dropped a restarted session into the middle of the cycle.

`blocked` and `finished` apply from `Idle` as well as from `Working`. An agent can go from sitting idle straight to needing a human, with no turn in between: a scheduled job that wakes and immediately asks for a password, or a producer whose `started` was dropped. Requiring an intervening `started` would swallow the red light in exactly the case the light exists for.

`finished` applies from `Blocked` for the same reason, and it is the everyday path rather than an edge case. A permission prompt ends when the human answers and the agent completes the turn: the Claude Code adapter sends `blocked` from its `Notification` hook and `finished` from `Stop`, with no `started` in between. Dropping that edge leaves the lamp red after every answered prompt, which breaks the [RFC 1 §8](rfc.md#8-aggregation) guarantee that a glance is trustworthy.

`blocked` applies from `Done` because a finished session that begins a new turn can block inside it. [RFC 1 §8](rfc.md#8-aggregation) requires the lamp to be red whenever any session is blocked, so this must not be swallowed either.

This table is mirrored in Go as `rfcSection7Table` in `internal/stoplight/color_test.go`, which asserts the code obeys every row and that the rows cover every state and event pair. **The two must change together.**

#### Sessions the relay has never seen

A producer that restarts mid-session, or a relay that restarts under a running producer, sends an event for a session ID nobody is tracking. The relay creates the session rather than rejecting the event, because losing a red light is worse than tracking a session whose start was missed.

The created session takes the state the event **itself** implies. It is not created as `Idle` and then transitioned, because `Idle` is green: a `blocked` for an unseen session would show a green lamp while a human is being waited on.

| Event for an unseen session | Resulting state | Lamp |
|---|---|---|
| `idle` | `Idle` | green |
| `started` | `Working` | yellow |
| `blocked` | `Blocked` | red |
| `finished` | `Done` | green |
| `ended` | not created | off |
| `Timeout` | not created | off |

`ended` and `Timeout` only end a session. There is nothing to expire for a session that was never tracked, so neither creates one and neither moves the frame.

This is `InitialState` in `color.go`. It is a separate function from `Next`, because "which state does this event start a session in" and "which state does this event move a session to" are different questions that happen to agree on four events out of six.

#### A label is not an event

The rule above is about EVENTS, and it does not extend to `stoplight task`. An event carries state: a `blocked` from a producer whose start was missed is a red light that genuinely exists, and creating the session is how the relay avoids losing it. A label carries no state at all.

So `SetOverride` on a session the relay has never seen creates **nothing**. Creating one meant choosing a state to create it in, and the only honest choice for "a human typed a name" was `Idle`, which is green. Naming a task against a relay with no live sessions therefore turned the lamp from off to green and held it there for the full timeout: an empty desk reporting finished work, against the [§8](rfc.md#8-aggregation) rule two sections below and against `SetOverride`'s own promise that naming a task cannot move the lamp. There is no light to lose here, so there is nothing to weigh against inventing one.

The name is not thrown away either. It is **parked** against the session ID and consumed by `Apply` the first time that session genuinely reports, which is what makes naming a task before it starts still work. A parked name applies once, and ages out on the same 30-minute silence rule as a session, so a name for work that never arrives does not sit in memory.

#### Field caps

[RFC 1 Appendix A](rfc.md#appendix-a-json-schema) caps `session_id` at 128 bytes, `label` at 256, `provider` at 64 and `cwd` at 4096. `Apply` **truncates** to these before storing. It does not reject: [§11](rfc.md#11-compatibility) requires the relay to be lenient, so an oversized field must not cost a producer its light.

Truncation happens before the ID is used as a map key, so repeat reports from the same oversized ID find the same session rather than making a new one each time. The cut lands on a rune boundary: the caps are in bytes, because the reason they exist is the firmware's fixed line buffer, but cutting mid-rune would put invalid UTF-8 on the wire.

These caps and `MaxFrameSessions` solve two halves of one problem and neither is sufficient alone. `MaxFrameSessions` bounds how MANY sessions a frame carries; these bound how LARGE each one is. A single 5,000-character `session_id` produced an oversized line with only one session in it, and because frames are sent only on change, one oversized frame is not one lost update: every later frame is oversized too, and the lamp holds its last colour indefinitely.

#### The session cap

Nothing in the protocol bounds how many distinct session IDs a producer may report, and a session lives for the full timeout after its last event. A loop of unique IDs therefore grew the map without limit for 30 minutes, and because every `Apply` sorted the whole list, the cost was quadratic: a 50,000-session probe did not finish in two minutes.

`MaxLiveSessions` caps the map at 256, far past any real desk. On overflow the least recently seen session is evicted, with one exception: **a blocked session is never evicted while a non-blocked one could go instead**. Dropping the session that needs a human in order to keep one that does not is exactly backwards for a device whose purpose is to show that a human is needed. Only when every session is blocked does the least recently seen blocked session go.

#### Change detection

Building a frame costs two sorts of the session list, under the write lock. [RFC 1 §7](rfc.md#7-session-lifecycle) asks every long-running agent to re-send its state every few minutes as a keepalive, so the common report is one that changes nothing and those sorts ran only to conclude so.

The tracker therefore keeps a dirty flag. Every write path sets it when it moves something a frame can show: a session's state, its displayed label, or the session set itself. Nothing else can move a frame, so a clean tracker provably renders the frame it rendered last and `commitLocked` returns false without building anything.

### Timeouts

Two, and they exist for different reasons.

**Session timeout, 30 minutes of silence.** A session that crashes never sends `Stop`, and without this one dead session holds the lamp red forever. Any event resets the countdown.

The check runs on **both** paths, `Sweep` and `Apply`, and this matters. [RFC 1 §7](rfc.md#7-session-lifecycle) makes expiry a MUST, and leaving it to `Sweep` alone made that MUST conditional on a ticker: between two sweeps a dead session still held the lamp red, so a slow, stalled or absent ticker meant a stale red for as long as the gap lasted. `Apply` therefore expires the silent before it folds in the report it was given. The reporting session is exempt from its own check, because the report it just sent IS its keepalive. `Sweep` is still needed for the quiet case, where no reports arrive at all and nothing else would notice the silence.

**Pin timeout, 15 minutes.** A pin stops the screen rotating. Without expiry you pin something, forget, and stop seeing every other session. A pin also clears the moment its session expires.

### Aggregation

The lamp shows the most urgent state across every live session.

```
Blocked  >  Working  >  Idle | Done
  red        yellow         green
```

No live sessions at all means lamps off, not green. An empty desk is not a finished task.

---

## Go types

```go
package stoplight

// Color is what a lamp shows. Ordered by urgency, so the zero value is
// the least urgent and Max() over a set gives the aggregate.
type Color uint8

const (
    ColorOff Color = iota
    ColorGreen
    ColorYellow
    ColorRed
)

// State is where a session is in its lifecycle.
type State uint8

const (
    StateIdle State = iota
    StateWorking
    StateBlocked
    StateDone
    StateExpired
)

// Color maps a state onto a lamp colour.
func (s State) Color() Color

// Label is the short word shown under the session name.
func (s State) Label() string   // "idle" "working" "needs you" "done"

// Event is something a producer reported, or a timeout the relay raised.
// Wire names are the lowercase forms in RFC 1: idle, started, blocked,
// finished, ended.
type Event uint8

const (
    EventIdle Event = iota
    EventStarted
    EventBlocked
    EventFinished
    EventEnded
    EventTimeout   // internal, never arrives over the wire
)

// ParseEvent maps a wire name onto an Event. Unknown names return
// ok == false and MUST be ignored rather than rejected, so a producer
// written against a later spec does not break an older relay.
func ParseEvent(s string) (Event, bool)

func (e Event) String() string

// Next returns the state this event moves to, and whether it changed
// anything. A false second return means the event was a no-op.
func (s State) Next(e Event) (State, bool)

// InitialState returns the state a session takes when the relay sees it
// for the first time, and whether the session should be created at all.
// A fresh session is created directly in the state the event implies,
// never as Idle-then-transitioned. ok is false for ended and Timeout,
// which must not bring a session into existence.
func InitialState(e Event) (State, bool)
```

### Session

```go
// Session is one unit of work the relay is tracking. It may come from
// any producer: an LLM CLI, a build, a script.
type Session struct {
    ID       string    // opaque, stable for the life of the session
    Label    string    // derived from cwd, or sent by the producer
    Override string    // set by `stoplight task`, wins over Label
    Provider string    // free text: claude-code, deepseek, ci, ...
    State    State
    Started  time.Time // fixes the rotation order
    LastSeen time.Time // drives the timeout
    Dir      string    // working directory, for label derivation

    // labelSent records that Label came from the producer rather
    // than from DeriveLabel. Unexported: tracker bookkeeping.
    labelSent bool
}

// Display is the label actually shown, override first.
func (s *Session) Display() string
```

A **derived** label is recomputed whenever the inputs derivation reads move, meaning `Dir` or `Provider`. A **sent** label never is: the producer said what it wanted the work called, and that wins permanently.

The distinction is what `labelSent` is for, and without it the fallback stuck. [RFC 1 §9](rfc.md#9-labels) derives a label from the git branch of `cwd`, but a producer's first report often carries no `cwd`, so derivation fell all the way through to the session ID. Once `Label` was non-empty nothing recomputed it, so a later report that finally supplied `cwd` updated `Dir` and left the screen showing an opaque session ID for the life of the session.

### Report

What a producer sends to the relay. The wire form is specified in
[RFC 1 §5](rfc.md#5-message-format); this is its Go shape.

```go
// Report is one event from one producer. Identical over HTTP and the
// unix socket.
type Report struct {
    SessionID string `json:"session_id"`
    Event     string `json:"event"`              // parsed via ParseEvent
    Label     string `json:"label,omitempty"`
    Provider  string `json:"provider,omitempty"`
    Detail    string `json:"detail,omitempty"`   // reserved
    Cwd       string `json:"cwd,omitempty"`
}

// Validate checks the required fields. Unknown event names are not an
// error here: the caller ignores them per RFC 1 §11.
func (r *Report) Validate() error
```

### Frame

What the relay sends to the light. One per change, carrying the whole set.

```go
// Frame is the complete display state at a moment.
type Frame struct {
    Color    Color          `json:"color"`   // aggregate, drives the lamps
    Sessions []FrameSession `json:"sessions"`
}

// FrameSession is one entry in the rotation.
type FrameSession struct {
    ID    string `json:"id"`
    Label string `json:"label"`
    State string `json:"state"`
    Color Color  `json:"color"`
}
```

### Tracker

The state machine, and the only place session state lives.

```go
// Tracker holds every live session and computes the aggregate.
// Safe for concurrent use.
type Tracker struct{ /* ... */ }

func NewTracker(sessionTimeout time.Duration) *Tracker

// Apply feeds in a hook notification. Returns true if the resulting
// Frame differs from the last one, which is the signal to transmit.
// Truncates oversized fields, and expires silent sessions first.
func (t *Tracker) Apply(r Report, now time.Time) (changed bool)

// SetOverride names a session. An empty label clears the override.
// An unknown session is NOT created: the name is parked and applied
// when that session first reports. Never moves the aggregate.
func (t *Tracker) SetOverride(sessionID, label string, now time.Time) (changed bool)

// Sweep expires silent sessions. Call on a ticker. Returns true if
// anything expired. Apply runs the same check, so a stalled ticker
// no longer means a stale red.
func (t *Tracker) Sweep(now time.Time) (changed bool)

// Frame renders the current state for transmission.
func (t *Tracker) Frame() Frame

// Aggregate is the most urgent colour across live sessions,
// ColorOff when there are none.
func (t *Tracker) Aggregate() Color

// Sessions returns live sessions ordered by start time.
func (t *Tracker) Sessions() []Session
```

### Transport

The seam that makes hardware optional.

```go
// Transport carries frames to a light. Serial and the virtual light
// implement it today, and BLE will, so nothing above this cares which
// is in use.
type Transport interface {
    // Connect blocks until connected or ctx is cancelled. It retries
    // internally; a returned error means give up, not try again.
    Connect(ctx context.Context) error

    // Send transmits one frame. An error means this frame was lost,
    // not that the transport is dead.
    Send(f Frame) error

    // Connected reports whether a light is currently reachable.
    Connected() bool

    // Close releases the port or link.
    Close() error

    // Name identifies the transport in logs and `stoplight status`.
    Name() string
}
```

Two implementations exist, and a third is designed:

| Type | Package | Status | Notes |
|---|---|---|---|
| `*serial.Transport` | `internal/transport/serial` | **Shipping** | USB serial. `serial.Discover` picks a device, `--serial` overrides it. |
| `*virtual.Transport` | `internal/light` | **Shipping** | Renders frames to the terminal. The fallback when no light is found. |
| `*ble.Transport` | `internal/transport/ble` | **Shipping** | Bluetooth Low Energy. Scans by service UUID, `--ble` and `--ble-name` select it. |

All three arrived without changing anything above the interface, which is what it was for. BLE was added last and `selectTransport` in `cmd.go` grew two flags; the relay, the tracker and the state machine were untouched.

`selectTransport` auto-discovers serial before BLE. A plugged-in cable states intent unambiguously where a radio in range does not, since a light on a neighbouring desk can advertise into the room; serial discovery is a filesystem glob costing microseconds where a scan costs seconds of radio time before the relay can listen; and serial is the debuggable link, so somebody with both attached is usually mid-debug. `--ble` overrides the order and does not fall back.

BLE is the one transport that cannot write a frame in a single call. A GATT write is capped by the negotiated ATT MTU, 20 bytes at worst against a frame of roughly 1200, so `ble.Transport.Send` splits a frame into chunks and the firmware reassembles on the newline delimiter. The contract both sides implement is `ble.ChunkContract`.

### Relay

The long-running process that ties it together.

```go
// Relay owns the tracker, the transport, and both ingest listeners.
type Relay struct{ /* ... */ }

type Config struct {
    Transport      Transport
    SessionTimeout time.Duration // default 30m
    SweepInterval  time.Duration // default 30s
    ListenAddr     string        // default 127.0.0.1:7373, loopback only
    SocketPath     string        // default ~/.local/state/stoplight/sock
    LogPath        string
}

func NewRelay(cfg Config) (*Relay, error)

// Run blocks until ctx is cancelled. It never returns on transport
// failure: a light that is off, asleep or out of range is an expected
// condition, and exiting would look like a crash to the service manager.
func (r *Relay) Run(ctx context.Context) error

// Status is what `stoplight status` prints.
func (r *Relay) Status() Status

type Status struct {
    Transport string
    Connected bool
    Sessions  []Session
    Aggregate Color
    Uptime    time.Duration
}
```

---

## Package layout

```
main.go                     command dispatch only, no logic
design.md                   this file

internal/
  stoplight/                core types and the state machine
    color.go                Color, State, Event, transitions
    session.go              Session, label derivation
    tracker.go              Tracker
    frame.go                Frame, FrameSession
    report.go               Report, the RFC 1 message

  relay/                    the long-running process
    relay.go                Relay, Run loop, sender, reconnect
    http.go                 the mux and all three handlers
    socket.go               unix socket, ingest only
    status.go               Status, StatusResponse, TaskRequest

  notify/                   the one-shot client
    notify.go               Send and SendTask, discard errors, exit 0 always

  adapter/                  one package per agent
    adapter.go              the Adapter interface, registry
    claudecode/             settings.json hooks, event mapping
      claudecode.go         the Adapter implementation
      object.go             ordered JSON objects, preserving key order
      settings.go           read, merge, write without clobbering

  service/                  keeping the relay alive
    service.go              Install, Uninstall, Start, Stop interface
    launchd.go              macOS
    systemd.go              Linux
    schtasks.go             Windows
    unsupported.go          every other GOOS

  transport/
    transport.go            the Transport interface
    serial/serial.go        USB serial
    ble/ble.go              BLE: retry, chunking, connection state
    ble/radio.go            everything touching tinygo.org/x/bluetooth
    ble/contract.go         the chunking contract the firmware implements

  light/
    virtual.go              terminal renderer, implements Transport

firmware/                   ESP32 firmware, built with the Arduino toolchain
enclosure/                  OpenSCAD and STLs
```

Adding support for another agent means adding a package under `adapter/` and registering it. No other package changes, and agents that need no adapter simply post to the HTTP endpoint.

### Dependency direction

```
   main
    │
    ├──▶ relay ──▶ stoplight ◀── notify
    │      │
    │      └──▶ transport ◀── light
    │
    ├──▶ adapter ──▶ adapter/claudecode
    └──▶ service
```

`internal/stoplight` imports nothing from the project. Everything else may import it. Nothing imports `relay` except `main`. That keeps the state machine testable in isolation, which matters because it holds the invariants.

An adapter imports `internal/adapter` for the interface and the registry, and nothing else from this project. `claudecode` does not import `stoplight` at all: it writes event names into a config file as strings, so it never needs the Go constants. Either way an adapter cannot reach the tracker, so it cannot invent state.

### Package APIs

```go
// internal/adapter
type Adapter interface {
    Name() string                      // "claude-code"
    Install(binPath string) error      // idempotent
    Uninstall() error                  // restores what it found
    Installed() (bool, error)
}

func Register(a Adapter)
func All() []Adapter
func Get(name string) (Adapter, bool)

// internal/service
type Manager interface {
    Install(binPath string) error
    Uninstall() error
    Start() error
    Stop() error
    Disable() error
    Running() (bool, error)
    Command() string   // the underlying launchctl/systemctl invocation
}
func New() (Manager, error)   // picks by GOOS

// internal/notify
func Send(addr string, r Report) error
// Posts to /v1/session. `notify` discards the error and exits 0. It is
// returned for tests, and for SendTask's caller.

func SendTask(addr string, t Task) error
// Posts to /v1/task. Unlike Send, this error IS reported: `stoplight
// task` is typed by a human who is owed an answer.

// internal/light
func NewVirtual(w io.Writer) *Transport
```

---

## Wire protocol

Two hops. The first is public and specified by [RFC 1](rfc.md); the second is private between this relay and this firmware.

```
  any producer ──HTTP or socket──▶ relay ──USB serial──▶ light
       │                                                   │
   RFC 1 §5                                         frame format below
   public contract                                  private, may change
```

### Producer to relay

Specified in full by [RFC 1 §4](rfc.md#4-transport) and [§5](rfc.md#5-message-format). Summarised here:

```
POST http://127.0.0.1:7373/v1/session
{"session_id":"a1","event":"blocked","label":"auth-api","provider":"deepseek"}
```

The same JSON is accepted on a unix socket at `~/.local/state/stoplight/sock`, for producers that spawn a process per event.

The relay MUST bind HTTP to loopback only. If nothing is listening, producers discard the error and continue. `stoplight notify` exits 0 unconditionally.

### The HTTP endpoints

The relay serves three paths, and the mux 404s anything else. Only the first is public: [RFC 1](rfc.md) specifies `/v1/session` and `/v1/task`, and `/v1/status` is a private management endpoint this implementation adds.

| Path | Method | Success | Errors | Purpose |
|---|---|---|---|---|
| `/v1/session` | `POST` | `204`, no body | `400`, `405`, `413` | Ingest. One report, one state transition. |
| `/v1/task` | `POST` | `204`, no body | `400`, `405`, `413` | Set or clear a session's screen label. No event, so it never moves the lamp. |
| `/v1/status` | `GET` | `200`, a `StatusResponse` | `405`, `500` | Read-only snapshot. What `stoplight status` prints. |

`400` is malformed JSON or a missing required field. `405` carries an `Allow` header naming the one method the path accepts. `413` is a body over `MaxBodyBytes`, 8KB.

The unix socket carries **ingest only**. There is no socket equivalent of task or status, because both are typed by a human through the CLI rather than fired from a hook, so neither has the per-event process-spawn cost the socket exists to avoid.

`/v1/status` is deliberately outside RFC 1. The RFC specifies what a producer sends, and nothing about `StatusResponse` is a producer concern: it exposes this relay's internal session bookkeeping, its transport name, and its uptime. Freezing that shape in a public spec would fix the relay's internals as a contract for third parties, which is exactly what the RFC's two-hop split exists to avoid. `stoplight status` and this document are its only consumers, and it may change with the implementation.

`/v1/task` is in the RFC for the opposite reason. It has a public client in `internal/notify`, its request body is two documented fields with no internal detail, and relabelling a session is a thing a third-party producer plausibly wants to do without shipping an adapter.

### Relay to light

Newline-delimited JSON over a serial port. The format is transport-agnostic, so a BLE characteristic will carry the same lines when that transport exists and the firmware will still parse one format.

This hop is **not** part of RFC 1. It is an implementation detail between the relay and the reference firmware, and it may change without a protocol version bump. Producers never see it.

```json
{"color":"red","sessions":[{"id":"a1","label":"auth-api","state":"needs you","color":"red"},{"id":"b2","label":"stoplight","state":"working","color":"yellow"}]}
```

| Field | Type | Notes |
|---|---|---|
| `color` | enum | Aggregate. `off`, `green`, `yellow`, `red`. Drives the lamps. |
| `sessions` | array | Ordered by start time. May be empty. |
| `sessions[].id` | string | Lets a pin survive a list update |
| `sessions[].label` | string | Top line. Firmware scrolls if it overflows. |
| `sessions[].state` | string | Bottom line |
| `sessions[].color` | enum | That session's own colour |

Every field is optional. A frame carrying only `color` moves the lamps and leaves the screen alone. Unknown fields are ignored, so either side can be updated without breaking the other.

Empty `sessions` with `color: "off"` means no live sessions: lamps dark, screen cleared.

### JSON Schema

```json
{
  "$schema": "https://json-schema.org/draft/2020-12/schema",
  "title": "Stoplight frame",
  "type": "object",
  "properties": {
    "color": { "enum": ["off", "green", "yellow", "red"] },
    "sessions": {
      "type": "array",
      "items": {
        "type": "object",
        "properties": {
          "id":    { "type": "string", "minLength": 1 },
          "label": { "type": "string" },
          "state": { "type": "string" },
          "color": { "enum": ["green", "yellow", "red"] }
        },
        "required": ["id"],
        "additionalProperties": true
      }
    }
  },
  "additionalProperties": true
}
```

`additionalProperties` is true deliberately. Forward compatibility beats strictness here, because the firmware and the app are updated separately and a stricter schema would turn a new field into a broken light.

### What the firmware owns

The relay sends state. The firmware decides how to show it. Rotation timing, scroll position, and which session is pinned all live on the device, so they keep working when the link drops.

---

## Invariants

Properties that must hold. Each one is a test.

**A pinned or rotating screen can never hide a red lamp.** The lamp is computed from every live session, independent of what the screen displays. This is the one that matters: the device's whole value is that a green glance is trustworthy.

**Aggregation ignores `provider`.** A red session is red whether it came from Claude Code, a shell script, or an agent that does not exist yet. One light, one aggregate.

**A producer can never break its caller.** `notify` exits 0 on every path: relay down, socket missing, malformed input, disk full. The reference clients in RFC 1 §13 discard errors for the same reason.

**The relay never exits on transport failure.** No light, cable unplugged, device gone: stay up and retry. Exiting looks like a crash to the service manager, which restarts it, which loops. The run loop polls `Transport.Connected` every second and re-connects, then re-sends the current frame so the light catches up.

**Unknown events and fields are ignored, not rejected.** A producer written against a later version of RFC 1 must not break an older relay.

**An unknown session is created, not rejected, in the state its event implies.** A producer that restarts mid-session may send `blocked` for a session the relay never saw. That session is created `Blocked`, so the lamp goes red. Creating it `Idle` and then applying the event would show green while a human is being waited on, which is the one failure the light exists to prevent. `ended` is the exception: there is nothing to expire, so no session is created.

**No live state refuses a work event.** `started`, `blocked` and `finished` are accepted from `Idle`, `Working`, `Blocked` and `Done` alike. An event says what the agent is doing now, so no earlier state can make it wrong. Every gate on the source state that has been tried here has lost a light: `finished` from `Blocked` held the lamp red after every answered permission prompt, and `blocked` from `Done` swallowed a red light on a session's second turn.

**Aggregation is order-independent.** The same set of sessions yields the same colour regardless of the order events arrived in.

**No live sessions means lamps off, not green.** Green means finished. Off means nothing running.

**A crashed session cannot hold the lamp.** The 30-minute sweep guarantees any state eventually reaches `Expired`, whatever the producer did.

**Adapter install and uninstall are idempotent.** Running twice changes nothing. Uninstall leaves the host's config as it was found, including other tools' entries.

**Frames are only sent on change.** `Apply` and `Sweep` return whether anything changed; the run loop transmits only then. A quiet desk is a quiet radio.

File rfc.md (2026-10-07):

# RFC 1: The Stoplight Agent Status Protocol

**Version** 1.0 · **Status** Draft · **Updated** September 2026

## Abstract

This document specifies how any agent reports its status to a Stoplight device. The protocol is a single HTTP endpoint carrying four core semantic events, plus one optional fifth, `idle`. It names no vendor, no model, and no framework, and it requires no library.

The protocol is deliberately small enough to implement in ten lines of any language. That is the whole design goal: a tool released next year should be able to drive a light built this year, without either knowing about the other.

Claude Code is one implementation, mapped in through an adapter like any other.

## Contents

- [1. Terminology](#1-terminology)
- [2. Model](#2-model)
- [3. Events](#3-events)
- [4. Transport](#4-transport)
- [5. Message format](#5-message-format)
  - [5.3 The task endpoint](#53-the-task-endpoint)
  - [5.4 The sync endpoint](#54-the-sync-endpoint)
- [6. Responses](#6-responses)
- [7. Session lifecycle](#7-session-lifecycle)
- [8. Aggregation](#8-aggregation)
- [9. Labels](#9-labels)
- [10. Adapters](#10-adapters)
  - [10.1 Discovery mechanisms](#101-discovery-mechanisms)
- [11. Compatibility](#11-compatibility)
- [12. Security](#12-security)
- [13. Reference implementations](#13-reference-implementations)

---

## 1. Terminology

The key words MUST, MUST NOT, SHOULD, SHOULD NOT and MAY are to be interpreted as described in RFC 2119.

**Agent** — any program doing work a human waits on. An LLM CLI, an IDE assistant, a build, a test suite.

**Session** — one unit of work with a beginning and an end. A conversation, a job, a run.

**Producer** — anything that sends events. An adapter, a script, a curl command.

**Relay** — the Stoplight process receiving events and driving the light.

**Device** — the physical light. Out of scope here; see [design.md](design.md).

---

## 2. Model

A producer reports **what happened**. The relay decides **what the light does**. Producers never send colours.

```
   ANY PRODUCER             RELAY                  DEVICE
   ────────────             ─────                  ──────
   an LLM CLI  ──┐
   an IDE agent──┤          tracks
   your script ──┼── HTTP ─▶ every    ── link ──▶  lamps
   a test run  ──┤          session                screen
   a CI job    ──┘          at once
```

Only the left hop is specified here. How a relay reaches its device is an implementation matter: the reference relay uses USB serial or BLE, and a producer sees no difference either way.

The left column is open-ended by design. This document describes what a producer sends, never what a producer is.

This split is the point. A producer that sent colours would need to know about every other session to choose correctly. By sending events instead, a producer needs to know only about itself, and the relay resolves conflicts.

---

## 3. Events

Four events. They are semantic, not vendor terms.

| Event | Meaning | Lamp |
|---|---|---|
| `started` | The agent began working | yellow |
| `blocked` | The agent needs a human | red |
| `finished` | The agent completed its work | green |
| `ended` | The session is over, stop tracking it | — |

A fifth is optional:

| Event | Meaning | Lamp |
|---|---|---|
| `idle` | Session exists, nothing happening | green |

Producers MUST send `started` before `blocked` or `finished` for a given session. A relay receiving `blocked` for an unknown session MUST create it rather than reject the event, because producers restart and relays restart and neither should lose a light.

A relay creating a session it has never seen MUST place it in the state the received event implies, and MUST NOT create it in a default state and then apply the event to that default. The two differ exactly where it matters: a session created idle and then sent `blocked` would show green.

| Event received for an unknown session | Relay MUST create the session as | Lamp |
|---|---|---|
| `idle` | idle | green |
| `started` | working | yellow |
| `blocked` | blocked | red |
| `finished` | done | green |
| `ended` | *not created* | — |

A relay MUST NOT create a session on `ended`, or on its own silence timeout. Both only end a session, and a session that was never tracked has nothing to expire.

`ended` is a courtesy. A relay MUST expire silent sessions on its own, because agents crash without saying goodbye.

### Choosing the right event

The distinction that carries the product is `blocked` versus `started`.

Send `blocked` when a human must act before work continues: a permission prompt, a clarifying question, a confirmation, a failed step needing a decision. Send `started` when the agent is thinking, generating, or running tools without needing anyone.

If you cannot tell the difference from inside your agent, send `started` and never `blocked`. A light that shows yellow honestly is worth more than one that shows red on a guess.

---

## 4. Transport

### 4.1 HTTP

The primary interface. The relay listens on loopback.

```
POST http://127.0.0.1:7373/v1/session
Content-Type: application/json
```

Port 7373 is the default and MUST be configurable. The relay MUST bind to loopback only unless explicitly configured otherwise.

This specification defines two paths under `/v1/`:

| Path | Method | Purpose | Section |
|---|---|---|---|
| `/v1/session` | `POST` | Report one event. The core of the protocol. | [§5](#5-message-format) |
| `/v1/task` | `POST` | Set or clear a session's screen label. Optional. | [§5.3](#53-the-task-endpoint) |

A relay MUST serve `/v1/session`. A relay SHOULD serve `/v1/task`. A relay MAY serve other paths under `/v1/` for its own management; those are outside this specification and a producer MUST NOT depend on them. The reference relay serves `GET /v1/status` on exactly that basis.

### 4.2 Unix socket

The relay MUST also accept the same JSON on a unix domain socket, default `~/.local/state/stoplight/sock`. This exists for producers that fire once per event and cannot afford TCP setup, such as shell hooks.

The message format is identical. One JSON object per connection.

The socket carries **session events only**. A relay MAY expose `/v1/task` over the socket and is not required to: relabelling is a human-driven action and does not have the once-per-event process-spawn cost the socket exists to avoid. The reference relay does not.

### 4.3 Choosing

| Use | When |
|---|---|
| HTTP | Almost always. Any language, any tool, trivially testable with curl. |
| Unix socket | High-frequency local hooks where process spawn cost matters |

---

## 5. Message format

```json
{
  "session_id": "a1b2c3",
  "event": "blocked",
  "label": "auth-api",
  "provider": "deepseek",
  "detail": "waiting for approval to write files"
}
```

| Field | Type | Required | Notes |
|---|---|---|---|
| `session_id` | string | yes | Stable for the session's life. Opaque to the relay. |
| `event` | enum | yes | One of `started`, `blocked`, `finished`, `ended`, `idle` |
| `label` | string | no | Shown on screen. See [§9](#9-labels). |
| `provider` | string | no | Free text: `claude-code`, `deepseek`, `kimi`, `ci`. Identifies the producer. |
| `detail` | string | no | Longer text. Reserved: the current device is too small to show it. |
| `cwd` | string | no | Working directory. Lets the relay derive a label if none is given. |

Unknown fields MUST be ignored, not rejected.

### 5.1 session_id

Any string, stable for the session. A UUID, a PID, a conversation ID, a branch name.

Two producers using the same `session_id` will be treated as one session. Producers SHOULD namespace it if collision is plausible, for example `deepseek:4417`.

### 5.2 provider

Free text, not an enum, so a new agent needs no change to this spec. The relay MAY show it on screen and MUST NOT use it for aggregation. One light shows one aggregate across every provider. A red DeepSeek session and a red Claude session are both just red.
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

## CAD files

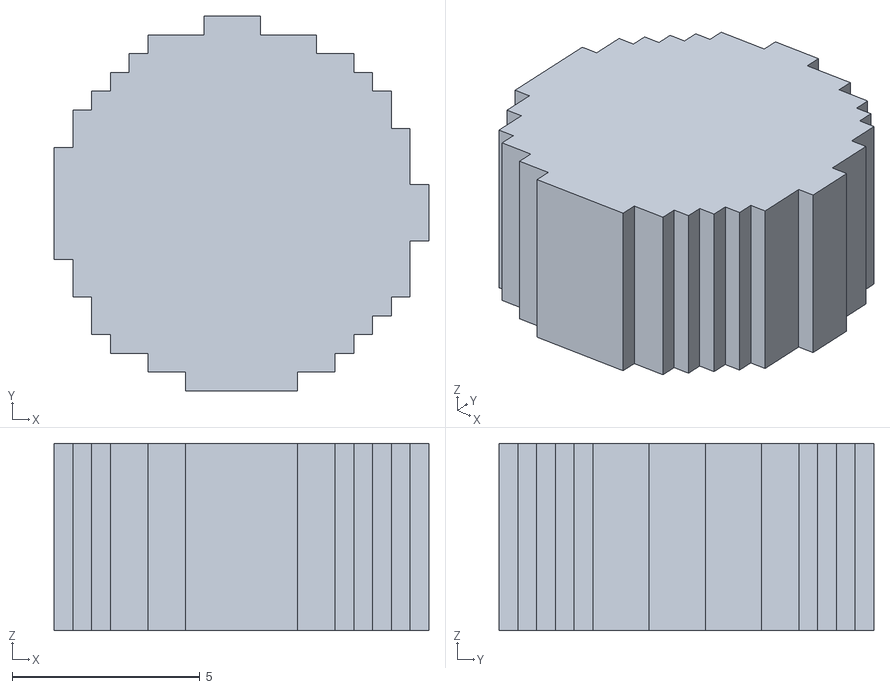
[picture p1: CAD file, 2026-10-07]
enclosure/stl/lens.stl
10.0 x 10.0 x 5.00

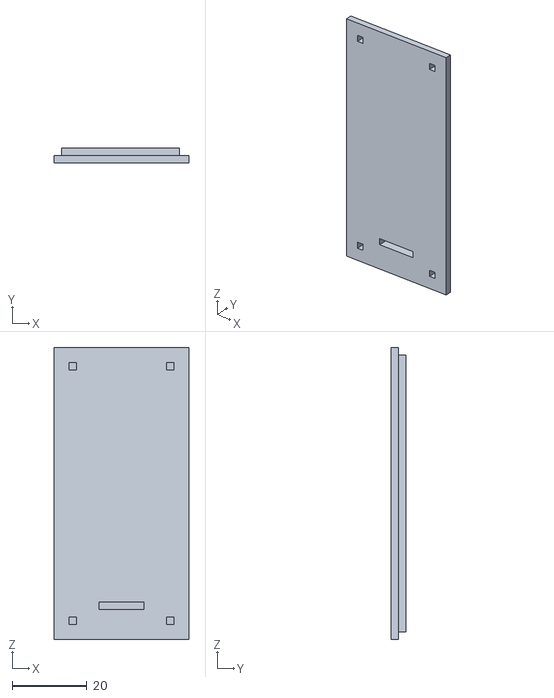
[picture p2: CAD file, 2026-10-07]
enclosure/stl/back.stl
36.0 x 4.00 x 78.0

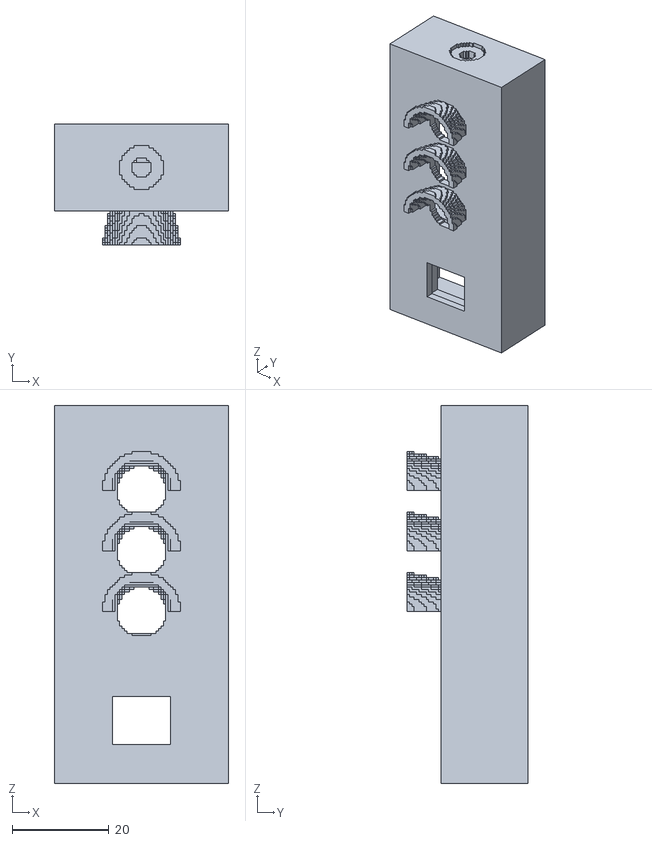
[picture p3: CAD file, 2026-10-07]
enclosure/stl/body.stl
36.0 x 25.0 x 78.0

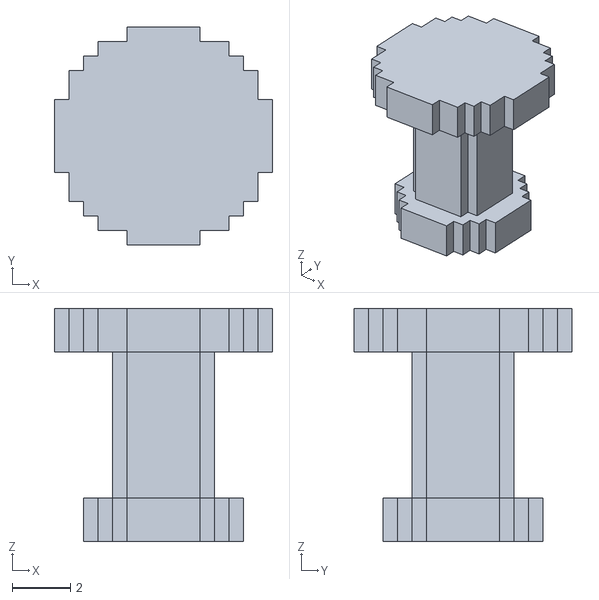
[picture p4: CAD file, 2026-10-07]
enclosure/stl/plunger.stl
7.50 x 7.50 x 8.00

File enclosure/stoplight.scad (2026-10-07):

// Stoplight enclosure — parametric source.
//
// Four parts: body, lens insert (print 3), back cover, button plunger.
// Set the `part` variable below, or render from the command line:
//   openscad -D 'part="body"' -o body.stl stoplight.scad
//
// DIMENSIONS LIVE IN params.json. The block below is generated from it by
// `python3 params.py`. Edit the JSON, run that, and both this file and
// gen_stl.py stay in step. Editing the block by hand will be overwritten.

part = "all";   // "body" | "lens" | "back" | "plunger" | "all"
$fn  = 64;

// <<< generated from params.json — do not edit by hand

/* [Print tuning] */
fit          = 0.2;         // gap between mating printed parts
slack        = 1.0;         // clearance around electronic components

/* [Components - measure yours] */
board_l      = 25.0;        // ESP32-C3 SuperMini
board_w      = 20.5;
board_h      = 6.0;
batt_l       = 35.0;        // LiPo 503035
batt_w       = 30.0;
batt_h       = 5.0;
chg_l        = 26.0;        // TP4057 charging module
chg_w        = 17.0;
chg_h        = 4.0;
led_dia      = 5.0;         // 5mm LED body
led_hole     = 5.2;         // through-hole for the LED
btn_body     = 6.0;         // tactile switch footprint
btn_h        = 5.0;         // switch height incl. actuator

/* [Button] */
plunger_dia  = 4.0;         // shaft through the top face
btn_recess   = 9.0;         // dished area around the plunger
btn_recess_d = 1.2;         // how far the dish sinks

/* [Board retention] */
tab_t        = 1.6;         // rail and tab thickness
tab_w        = 4.0;         // how far each tab reaches over the board

/* [Visors] */
visor_out    = 7.0;         // projection from the front face
visor_t      = 1.6;         // wall thickness

/* [Openings] */
screen_w     = 12.0;        // window over the OLED
screen_h     = 10.0;
usb_w        = 10.0;        // USB-C cutouts
usb_h        = 6.0;

/* [Shell] */
wall         = 2.0;
top_wall     = 3.0;         // thicker: the button loads it
inner_d      = 14.0;        // front-to-back cavity
lens_dia     = 10.0;
lens_deep    = 12.0;        // bore depth in the body
lens_thick   = 5.0;         // insert thickness
lens_pitch   = 12.5;        // centre to centre
btn_sect     = 8.0;         // height of the button section
scr_sect     = 26.0;        // height of the screen section

/* [Derived] */
lamp_sect    = 3 * lens_pitch + 6.5;
inner_w      = batt_w + 2 * slack;   // battery is widest
outer_w      = inner_w + 2 * wall;
outer_d      = inner_d + 2 * wall;
outer_h      = btn_sect + lamp_sect + scr_sect;
lamp_mid     = scr_sect + lamp_sect / 2;

// >>> end generated

// Centre height of lamp i, 0 = top (red). Used by both bores and visors.
function lamp_z(i) = lamp_mid + lens_pitch - lens_pitch * i;

echo(str("Outer: ", outer_w, " x ", outer_h, " x ", outer_d, " mm"));

/* ---------------------------------------------------------------- */

module lens_bore(z) {
    // Bore for the lens insert, plus the LED hole behind it.
    translate([outer_w / 2, -1, z])
        rotate([-90, 0, 0])
            cylinder(d = lens_dia + fit, h = wall + lens_deep + 1);
    translate([outer_w / 2, wall + lens_deep - 0.1, z])
        rotate([-90, 0, 0])
            cylinder(d = led_hole, h = 6);
}

module visor(z) {
    // Hood over a lamp: projects forward, open underneath so the lamp stays
    // readable from the desk while shaded from a monitor above.
    translate([outer_w / 2, 0, z])
        difference() {
            rotate([90, 0, 0])
                cylinder(h = visor_out, r1 = lens_dia / 2 + visor_t,
                         r2 = lens_dia / 2 + visor_t + 1.5);
            rotate([90, 0, 0])
                translate([0, 0, -0.1])
                    cylinder(h = visor_out + 0.2, r1 = lens_dia / 2,
                             r2 = lens_dia / 2 + 1.5);
            translate([-15, -visor_out - 1, -15]) cube([30, visor_out + 2, 15]);
        }
}

module board_retention() {
    // Rails, ledge and front tabs. Rendered after the cavity is cut.
    bd_x0 = (outer_w - board_w) / 2 - fit;
    bd_x1 = (outer_w + board_w) / 2 + fit;
    bd_y  = wall + 0.6;
    bd_z0 = 4.0;
    bd_z1 = bd_z0 + board_l + fit;

    for (x = [bd_x0 - tab_t, bd_x1])
        translate([x, bd_y, bd_z0])
            cube([tab_t, board_h + tab_t, bd_z1 - bd_z0]);

    translate([bd_x0 - tab_t, bd_y, bd_z0 - tab_t])
        cube([bd_x1 - bd_x0 + 2 * tab_t, board_h + tab_t, tab_t]);

    translate([bd_x0 - tab_t, bd_y, bd_z1])
        cube([bd_x1 - bd_x0 + 2 * tab_t, board_h + tab_t, tab_t]);

    for (z = [bd_z0 + 3.0, bd_z1 - 3.0 - tab_w]) {
        translate([bd_x0, bd_y - 1.2, z])          cube([tab_w, 1.2, tab_w]);
        translate([bd_x1 - tab_w, bd_y - 1.2, z])  cube([tab_w, 1.2, tab_w]);
    }
}

module body() {
    union() {
    difference() {
        // Outer shell.
        cube([outer_w, outer_d, outer_h]);

        // Main cavity, open at the back. The thick top_wall lands under the
        // button at the top face; the base keeps the plain wall.
        translate([wall, wall, wall])
            cube([inner_w, inner_d + wall, outer_h - top_wall - wall]);

        // Three lamp bores, centred in the lamp section so the top bore
        // clears the button pocket and the bottom one clears the screen.
        for (i = [0 : 2])
            lens_bore(lamp_z(i));

        // Button: pocket for the switch, hole for the plunger, and a dish
        // around it so the cap sits below the top face.
        translate([outer_w / 2, outer_d / 2, outer_h - top_wall - btn_h])
            cube([btn_body + fit, btn_body + fit, btn_h + 1], center = true);
        translate([outer_w / 2, outer_d / 2, outer_h - top_wall - 0.5])
            cylinder(d = plunger_dia + fit, h = top_wall + 1);
        translate([outer_w / 2, outer_d / 2, outer_h - btn_recess_d])
            cylinder(d = btn_recess, h = btn_recess_d + 1);

        // Screen window in the front face.
        translate([(outer_w - screen_w) / 2, -1, scr_sect / 2 - screen_h / 2])
            cube([screen_w, wall + 2, screen_h]);

        // USB-C openings in the base: board, then charger.
        translate([(outer_w - usb_w) / 2 - 6, outer_d / 2 - 4, -1])
            cube([usb_w, usb_h, wall + 2]);
        translate([(outer_w - usb_w) / 2 + 6, outer_d - wall - 5, -1])
            cube([usb_w, usb_h, wall + 2]);

        // Back cover rebate.
        translate([wall - fit, outer_d - wall, wall])
            cube([inner_w + 2 * fit, wall + 1, outer_h - 2 * wall]);
    }

    // Rib beside the button pocket, so the top does not flex.
    translate([outer_w / 2 - btn_body, outer_d / 2 - 1.5, outer_h - top_wall - btn_h - 3])
        cube([2, 3, 3]);
    translate([outer_w / 2 + btn_body - 2, outer_d / 2 - 1.5, outer_h - top_wall - btn_h - 3])
        cube([2, 3, 3]);

    // Screw bosses for the back cover.
    for (x = [wall + 3, outer_w - wall - 3], z = [wall + 3, outer_h - wall - 3])
        translate([x, outer_d - wall - 3, z])
            difference() {
                cylinder(d = 5, h = 3, center = true);
                cylinder(d = 1.7, h = 4, center = true);   // M2 self-tap
            }

    // Board rails and tabs, added after the cavity is cut.
    board_retention();

    // Visors, one per lamp.
    for (i = [0 : 2])
        visor(lamp_z(i));
    }
}

module lens() {
    // Diffuser. Print at 15% infill, 2 perimeters, no top or bottom layers.
    difference() {
        cylinder(d = lens_dia - fit, h = lens_thick);
        translate([0, 0, -0.1])
            cylinder(d = led_hole + 0.3, h = 3);
    }
}

module back() {
    difference() {
        union() {
            cube([inner_w + 2 * wall, wall, outer_h - 2 * wall + 2 * wall]);
            // Lip that sits inside the rebate.
            translate([wall, -wall + 0.1, wall])
                cube([inner_w - 2 * fit, wall, outer_h - 2 * wall]);
        }
        // Screw holes.
        for (x = [wall + 3, inner_w + wall - 3], z = [wall + 3, outer_h - wall - 3])
            translate([x, -1, z])
                rotate([-90, 0, 0])
                    cylinder(d = 2.2, h = wall + 2);
        // Vent slot near the charger.
        translate([inner_w / 2 - 6, -1, wall + 6])
            cube([12, wall + 2, 2]);
    }
}

module plunger() {
    // Drops into the top face and rests on the switch actuator.
    cylinder(d = 4.0 - fit, h = top_wall + 2);
    translate([0, 0, top_wall + 2])
        cylinder(d = 6.0, h = 1.2);          // cap, sits proud of the case
    translate([0, 0, -1.5])
        cylinder(d = 5.5, h = 1.5);          // shoulder, stops it falling out
}

/* ---------------------------------------------------------------- */
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

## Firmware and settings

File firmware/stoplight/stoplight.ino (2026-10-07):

// stoplight.ino - a physical traffic light showing AI agent status.
//
// Board: ESP32-C3 SuperMini with onboard 0.42 inch OLED.
// Flash as "ESP32C3 Dev Module", USB CDC On Boot ENABLED, 4MB, QIO.
// See firmware/readme.md, especially the note about the screen offset.
//
// The relay sends the whole session list as one line of JSON per change.
// This firmware owns rotation, scrolling and the pin, so all three keep
// working when the link drops. See design.md, "What the firmware owns".
//
// THE INVARIANT THAT MATTERS, from design.md:
//
//   A pinned or rotating screen can never hide a red lamp.
//
// It is enforced structurally rather than by care. The aggregate colour goes
// from the parsed frame to Lamps::set() in one statement below, and Display
// is never consulted. Display has no reference to Lamps and no way to obtain
// one. To break the guarantee you would have to add a Lamps call inside the
// display module, which is a conspicuous change rather than an easy mistake.
//
// Nothing here blocks. There is no delay() anywhere in loop(), because a
// blocking wait would stall serial reads and make the button feel dead.

#include <Arduino.h>
#include <Wire.h>

#include "blelink.h"
#include "button.h"
#include "display.h"
#include "lamps.h"
#include "protocol.h"

// I2C for the onboard panel. These are not the core's default pins, so Wire
// must be told about them explicitly before the display starts.
#define PIN_SDA 5
#define PIN_SCL 6
#define OLED_ADDR 0x3C  // if the screen stays blank, try 0x3D. See the readme.

// Blank the screen after this long with no frame, and wake on the next one.
// The lamps stay lit: the colour is still true, and it is the reason the
// device exists. Only the screen sleeps.
#define SCREEN_IDLE_MS (5UL * 60UL * 1000UL)

Lamps lamps;
Display display;
Button button;
BleLink ble;

// ONE reader for BOTH transports, which is the point.
//
// A BLE chunk is indistinguishable from a partial serial read: both are a
// slice of bytes at an arbitrary offset, and the '\n' in the payload is the
// only frame delimiter either one has. Feeding both into the same LineReader
// is what makes that true in code rather than only in the contract. Two
// readers would be two chances to disagree about the frame format, and the
// BLE one would be the one nobody watches.
//
// It also means a frame may arrive half over USB and half over the radio.
// That is nonsense in practice, but it is harmless: the bytes concatenate,
// the line either parses or it does not, and a corrupt line costs one update.
LineReader reader;

// One reusable Frame. Parsing into a static buffer avoids putting a ~1KB
// struct on the stack on every line.
Frame frame;

uint32_t lastFrameAt = 0;

void setup() {
  // The CDC receive buffer must hold a whole frame, and the default does not.
  //
  // The default is 256 bytes. A frame carrying four sessions with real UUID
  // ids runs to about 500, so the tail of every large frame was dropped on
  // the floor before loop() could read it. The loss is SILENT: available()
  // reports what arrived, never what was discarded, so the reader sees a
  // short line, parses it happily, and the screen shows fewer sessions than
  // were sent. Nothing anywhere reports an error.
  //
  // No host test can catch this. The stubs have no transport and no buffer,
  // so the parser reads every byte the test hands it and all eight sessions
  // arrive. It reproduces only on hardware, and only above 256 bytes.
  //
  // Sized to SL_LINE_MAX so the buffer can hold the largest line the reader
  // will accept. Must be called BEFORE begin(), which is where the buffer is
  // allocated; afterwards it is ignored and the default stands.
  Serial.setRxBufferSize(SL_LINE_MAX);

  // USB CDC. Nothing waits on the port: the device must run standalone on a
  // battery with no host attached, so a "wait for serial" loop would hang it.
  Serial.begin(115200);

  Wire.begin(PIN_SDA, PIN_SCL);

  lamps.begin();
  display.begin();
  button.begin();

  // The radio starts unconditionally, alongside serial rather than instead
  // of it. Which link the relay uses is the relay's choice, and a light that
  // answered only one of them would need a build flag to switch, which is a
  // decision made at flash time about something discovered at run time.
  ble.begin();

  lastFrameAt = millis();
}

// feedByte hands one byte to the reader and acts on a completed line. It is
// the whole of frame handling, and it is transport-agnostic on purpose: the
// serial drain and the BLE drain both call it, so neither link can develop
// its own idea of what a frame is.
//
// Returns true when the byte produced something worth counting as activity,
// which is a complete frame or a salvaged aggregate.
static bool feedByte(char c, uint32_t now) {
  if (!reader.feed(c)) {
    // An oversized line yields no frame, but it may still have given up its
    // aggregate. Move the lamps on it and leave the screen alone: the
    // session list was unusable, and a stale label beats a wrong one.
    // Losing the labels is acceptable; losing the lamp is not.
    Color salvaged;
    if (reader.overflowColor(&salvaged)) {
      lamps.set(salvaged);
      return true;
    }
    return false;
  }

  // A complete line. Parse it, and ignore it if it was not usable.
  if (!parseFrame(reader.line(), &frame)) {
    return false;
  }

  // THE LAMPS. Straight from the frame's aggregate, with no reference to
  // the display, the rotation index, or the pin.
  //
  // A frame with no "color" key leaves the lamps where they are, because
  // absent means "no instruction", not "off".
  if (frame.hasColor) {
    lamps.set(frame.color);
  }

  // THE SCREEN. Separately, and it cannot reach back to the lamps.
  display.applyFrame(frame, now);

  return true;
}

void loop() {
  const uint32_t now = millis();

  // 1. Drain both transports. Bounded per iteration so that a fast writer
  // cannot starve the button and the display: the reader keeps its partial
  // line between iterations, so stopping early is free.
  //
  // The two drains share a budget rather than having one each, so a busy
  // radio and a busy cable together still cannot hold the loop for longer
  // than one link could alone.
  uint16_t budget = 256;

  while (Serial.available() > 0 && budget-- > 0) {
    int c = Serial.read();
    if (c < 0) {
      break;
    }
    if (feedByte((char)c, now)) {
      lastFrameAt = now;
    }
  }

  while (ble.available() > 0 && budget-- > 0) {
    int c = ble.read();
    if (c < 0) {
      break;
    }
    if (feedByte((char)c, now)) {
      lastFrameAt = now;
    }
  }

  // 2. The button.
  //
  // A press is activity, exactly like a frame. Without this, step 4 below would
  // blank the screen SCREEN_IDLE_MS after the last frame no matter how recently
  // the button was pressed, so the press that togglePin/advance uses to wake a
  // sleeping screen is undone on this same pass and the button cannot bring the
  // screen back. Treating the press as activity keeps the woken screen up for a
  // fresh idle interval, which is the whole point of pressing it.
  switch (button.update(now)) {
    case BUTTON_SHORT_PRESS:
      display.togglePin(now);
      lastFrameAt = now;
      break;
    case BUTTON_LONG_PRESS:
      display.advance(now);
      lastFrameAt = now;
      break;
    default:
      break;
  }

  // 3. Rotation and scrolling.
  display.tick(now);

  // 4. Blank the screen after a quiet spell. Unsigned subtraction keeps this
  // correct across the millis() rollover at about 49 days.
  if (!display.asleep() && (uint32_t)(now - lastFrameAt) >= SCREEN_IDLE_MS) {
    display.sleep();
  }
}

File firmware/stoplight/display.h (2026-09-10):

// display.h - the screen: rotation, marquee scrolling, and the pin.
//
// THE PANEL, AND THE ONE THING THAT WILL WASTE YOUR EVENING:
//
// The 0.42 inch OLED is a 72x40 window driven by an SSD1306 that addresses a
// 128x64 buffer. The visible area sits at offset (13, 14) inside that buffer.
// Draw at 0,0 with a generic driver and the pixels land off-panel, and the
// screen looks dead rather than misconfigured. U8G2_SSD1306_72X40_ER_F_HW_I2C
// applies the offset, which is why that exact constructor is not negotiable.
// See firmware/readme.md.
//
// WHAT THIS MODULE OWNS, per design.md "What the firmware owns": rotation
// timing, scroll position, and which session is pinned. All of it survives a
// dropped link, because the relay sends state and the device decides how to
// show it.
//
// WHAT IT DOES NOT OWN: the lamps. There is no Lamps reference in this
// header or its implementation. The pin cannot reach them.
//
// THE BLANK SCREEN BUG, AND WHY THE FIX LOOKS BRUTE-FORCE:
//
// The panel used to go dark permanently in normal use. The lamps kept
// working, frames kept arriving, and an I2C scan still found the panel at
// 0x3C -- only a reflash brought the screen back.
//
// The cause: begin() ran once at boot and never again. An SSD1306 holds its
// entire configuration in volatile registers, so any disturbance that
// rewrites them -- a brownout while the wires are moved, a glitch on the bus
// corrupting a command byte -- leaves a panel that is powered and addressable
// but no longer configured to show anything. The firmware carried on pushing
// buffers into it forever. A reflash "fixed" it only because it re-ran
// begin().
//
// THE PART THAT DECIDES THE DESIGN: the panel still ACKs its address while
// blank. This was measured on the bench, not assumed. Both reproductions
// below reported ack=1 the entire time the screen was dark:
//
//   0xAE (display off) latched behind U8g2's back  -> dark, ACKs, never returns
//   0xA8 0x00 (multiplex ratio corrupted)          -> dark, ACKs, never returns
//
// So there is nothing to detect. Probing 0x3C with beginTransmission and
// endTransmission reports a healthy panel while the user is looking at a
// dead one, and U8g2's send-path return values say the bus write succeeded,
// because it did. A detect-then-recover design cannot see this fault.
//
// Hence: re-assert the initialisation unconditionally on a timer and never
// ask whether it was needed. Re-running the init on a working panel is a
// no-op that costs about a millisecond, so the cheap unconditional fix is
// strictly better than an expensive detector that does not work.

#ifndef STOPLIGHT_DISPLAY_H
#define STOPLIGHT_DISPLAY_H

#include <Arduino.h>
#include <U8g2lib.h>

#include "protocol.h"

// Timing, all from the readme.
#define DISP_ROTATE_MIN_MS 3000   // minimum slot time; scrolling may extend it
#define DISP_SCROLL_HOLD_START_MS 1000  // let the first characters be read
#define DISP_SCROLL_HOLD_END_MS 800     // pause at the end before resetting
// One pixel per step. Raised from 90ms to 68ms when the label went to the
// 10x20 font: wider glyphs mean more overhang for the same text, so the old
// rate made a long branch name take an uncomfortably long time to get through.
// 68ms is about a third faster without tipping into frantic.
#define DISP_SCROLL_STEP_MS 33
#define DISP_PIN_TIMEOUT_MS (15UL * 60UL * 1000UL)  // 15 minutes

// How often the panel's initialisation is re-asserted. See "THE BLANK SCREEN
// BUG" below. Ten seconds is chosen so that the worst case a user ever sees
// is a screen that is dark for ten seconds and then fixes itself, which reads
// as a flicker rather than as a failure. The cost is one init sequence, about
// thirty bytes over a 400kHz bus, roughly a millisecond, every ten seconds.
#define DISP_REINIT_INTERVAL_MS 10000UL

// Layout. Two rows, not three. The panel is 72x40:
//
//   y=0    the header: a pin marker and one dot per session
//   y=14   the label, in DISP_LABEL_FONT, scrolled if it overflows
//
// The state line ("working", "needs you") was removed to give the label the
// bottom two thirds of the panel. The state is already on the lamps, in
// colour, from across the room -- spending a third of a 40px screen to spell
// out what the red LED is already saying was the worst-value row of the three.
//
// DISP_CHAR_W must match the advance of DISP_LABEL_FONT, because the overflow
// and scroll maths are done in characters times advance rather than by asking
// U8g2 for a string width. The two are changed together or the marquee scrolls
// the wrong distance. u8g2_font_10x20_tf advances 10px per glyph, so a 72px
// line holds 7 characters.
#define DISP_W 72
#define DISP_H 40
#define DISP_LABEL_FONT u8g2_font_9x18_tf
#define DISP_CHAR_W 9
#define DISP_LABEL_Y 26
// Top of the label band. The label BASELINE is DISP_LABEL_Y; glyphs sit
// above it, so clipping from the baseline would cut off every character.
#define DISP_LABEL_BAND_TOP 8
#define DISP_VISIBLE_CHARS (DISP_W / DISP_CHAR_W)

// Position dots. One per session across the header, the current one filled.
// This replaces the "2/4" counter: at a glance the shape of the row says both
// how many sessions there are and where you are in the cycle, without the eye
// having to read and compare two digits.
//
// Radius 2 makes a 5px circle, which is the same visual weight as the 5x7
// digits it replaces. At 7px spacing the widest case, SL_MAX_SESSIONS of 8,
// spans 7*7+5 = 54px and still leaves room for the pin marker in front of it.
#define DISP_DOT_R 2
#define DISP_DOT_SPACING 7
#define DISP_DOT_CY 3   // centre y: a 5px circle sits in rows 1..5
#define DISP_PIN_X 0    // the pin marker keeps the top-left corner
#define DISP_DOTS_X 8   // dots start clear of the marker, marker or not
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

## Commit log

2026-08-19 docs: add project readme and repository ignores
    The user-facing entry point: what the device is, the five-minute path to
    a working light, the HTTP and socket API, and the install flow across
    macOS, Linux and Windows.
    The ignores keep generated output out of history entirely. firmware/build
    holds the arduino-cli artifacts, some 20 binaries including a 350KB .elf
    and a .map, and enclosure/stl holds 10.9MB of models. Both are
    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
2026-08-24 docs: add design document and RFC 1
    design.md is the architecture: the state machine, what the relay owns
    against what the firmware owns, the transition table, and the reasoning
    behind the aggregate lamp and the rotating screen.
    rfc.md is the wire protocol. It is a separate document because the
    protocol is not Claude-specific: events are named semantically so any
    agent can drive the light, and the RFC is what a third-party producer
    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
2026-09-03 feat(enclosure): add parametric case models and generators
    Four printable parts - body, back, lens and plunger - driven from a
    single source. params.json holds every dimension; stoplight.scad reads
    them, gen_stl.py renders the STLs, and gen_docs.py regenerates the
    dimension tables in the readme.
    Nothing is duplicated by hand, and test_params.py proves it: the .scad,
    the STL generator and the readme tables are all checked against the JSON
    so none can drift from it.
    The models are parametric because the enclosure has to follow parts you
    are holding rather than numbers from a product listing. Measure the real
    button, change one variable, reprint.
    The rendered STLs are generated output and st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
    [stoplight.scad]
2026-09-07 feat(firmware): add ESP32-C3 firmware with host test harness
    Drives three PWM lamps, a 72x40 OLED, rotation, marquee scrolling and
    the button over USB serial. Nothing blocks: there is no delay() in
    loop(), every timer is an unsigned millis() comparison, so elapsed-time
    maths stays correct across the 49-day rollover.
    The JSON parser is hand written rather than ArduinoJson. Every buffer is
    fixed size and lives in the object, so there is no allocator and no heap
    fragmentation over a multi-day uptime. Unknown keys are skipped at any
    depth, so adding a field to the relay cannot break a light flashed
    today, and a truncated line still applies whatever parsed before the
    break.
    lamps and display sh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
    [Arduino.h, display.h, lamps.cpp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]
2026-09-10 feat: add relay, state machine, transports and service install
    The Go half of the project, and the first commit that builds.
    internal/stoplight holds the state machine, session tracking and label
    derivation. The transition table from design.md is mirrored as
    rfcSection7Table and asserted row by row, so the document and the code
    cannot disagree silently. The tracker caps live sessions at 256 and
    frames at 8 entries while computing the aggregate over every session: a
    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
2026-09-10 feat: add full-state sync so a poll can end what hooks cannot see
    Hooks report only what an agent chooses to report, so what they omit is
    invisible. A session that ends without a final event stays lit, and a
    session the agent never announced is never named. Observed on a real
    desk: the relay tracked 8 sessions against 2 the agent knew about, and
    two of the phantoms were red, so the lamp claimed a human was needed when
    nothing was waiting.
    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
2026-09-10 fix(adapter): resolve the agent binary without relying on PATH
    The poll failed on a machine where typing 'claude' worked:
    poll claude-code: claude: exec: "claude": executable file not
    found in $PATH
    The relay normally runs as a launchd or systemd service, and a service
    does not inherit the PATH of the shell that installed it. Claude Code
    installs to ~/.local/bin, which is on an interactive PATH and absent from
    the service's, so polling silently did nothing while the same binary
    polled fine when run by hand.
    The failure was contained rather than loud, which is correct and is also
    why it could hide: a failed poll leaves the tracker alone, so the light
    kept showing whatever the hooks had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
2026-09-10 fix(adapter): let the relay derive a label when a session is untitled
    An untitled Claude Code session reports its own ID as its name, so the
    glass showed '339d206f' and '2026a22b'. A hex ID is the worst thing a
    seven-character screen can carry, and the session showing it was the one
    blocked and waiting for input: identifying the session that wants you is
    the entire job of the screen.
    Passing the ID through also froze it. RFC 1 section 9 never recomputes a
    label a producer SENT, only a derived one, so a session labelled with its
    own ID could never pick up a better label even once its cwd was known.
    Reporting an empty label instead hands the decision to DeriveLabel, which
    reads the git branc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
2026-09-10 feat(firmware): hold the screen on red until it is resolved
    The lamp says something needs a human. The screen has to say WHICH, and it
    did not: a session that turned red jumped to the screen, held for one
    three-second interval, then rotated away while still red. The screen was
    useless for its one job at the moment it mattered most, and the only way
    to learn what was blocked was to watch a cycle and catch it.
    Rotation is now confined to the red sessions while any session is red.
    Normal rotation resumes as soon as nothing is red.
    Rotating among the reds rather than holding the first one is the part that
    matters. A plain hold pins the screen to whichever session went red first,
    so a second bl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
    [display.h, test_main.cpp]
2026-09-11 feat(firmware): implement the BLE peripheral half of the transport
    The host side of BLE has been written and tested since before this; the
    ESP32 advertised nothing, so the light was a wired device and steps 5 and
    6 of the roadmap both waited on this.
    blelink.cpp publishes the service and characteristic from
    ble.ChunkContract, advertises the service UUID, and queues received bytes.
    It does NOT parse. The contract is explicit that a BLE chunk is
    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
2026-09-11 docs: record that BLE works on both ends
    The docs described a state that stopped being true when the firmware
    peripheral landed. roadmap.md called step 5 half done and said the ESP32
    advertised nothing; firmware/readme.md listed BLE under what nobody has
    looked at yet.
    roadmap.md: step 5 is Done, verified on hardware. The status line now
    says the radio is closed and the gap is power. Step 6 is described as
    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
2026-09-11 chore: ignore the in-place relay binary and the worktree directory
    'go build -o stoplight .' is the obvious thing to type and drops 10MB in
    the repo root, where it sits in git status and is one 'git add -A' away
    from being committed.
    The pattern is anchored. Without the leading slash 'stoplight' would also
    match firmware/stoplight/, silently excluding the entire firmware source
    directory, which is the kind of mistake that is only noticed once the
    files are missing from a fresh clone.
    .claude/worktrees/ is local scratch for the same reason: only
    settings.local.json was ignored, so a worktree created in place showed as
    untracked.
2026-09-26 feat: let `stoplight install` pin the service to BLE
    The relay command already accepts --ble and --ble-name, but install
    parsed no transport flags and the launchd, systemd and schtasks
    definitions all hardcoded a bare `relay`. The service could therefore
    only auto-discover, which is serial-first whenever a USB cable is
    plugged in, so there was no durable way to run the background service on
    Bluetooth.
    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
2026-10-07 fix(enclosure): put the 3mm wall under the button and ship the STLs (#34)
    The main cavity started at z=top_wall and ended at outer_h-wall, so the thick 3mm top_wall landed at the base and the thin 2mm wall sat under the button at the top face. readme.md:152 requires the top face at 3mm because the button loads it. The two generators both had the defect and both matched each other, so a probe found z=2.5 solid and z=75.5 empty, which is inverted. The cavity now runs from z=wall to z=outer_h-top_wall, so the base keeps the 2mm wall and the top gets the 3mm wall under the button. This is fixed in stoplight.scad and gen_stl.py together, so the two models still agree.
    The STLs the readme promise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
    [back.stl, body.stl, lens.stl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]
2026-10-07 fix(tracker): order hook reports by arrival so a stale poll cannot reverse them (#20)
    Reports to /v1/session carry no observation time, so a hook-created session
    held a zero observedAt. Both Reconcile ordering guards compare against that
    stamp (tracker.go:266, :300), and a zero time loses every comparison — so the
    RFC 5.4 ordering rule protected only sessions a sync itself created. A poll
    that started before a hook fired and returned after it would reverse the hook:
    a Notification hook landing blocked, then a stale poll listing the session as
    working, moved the lamp from red to yellow while a human was being waited on.
    The same gap deleted a hook-created session that started after the poll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
2026-10-07 fix(service): restart on reinstall and check ownership before stop (#25)
    Reinstalling with new relay args never restarted a running relay on systemd or Task Scheduler. cmdInstall writes the definition and then calls Start, but systemd's `start` and schtasks' `/Run` are no-ops on a service that is already up, so the old process kept running on the previous command line until the next login. systemd Install now issues `try-restart`, which restarts the unit only when it is already active, and schtasks Install ends and re-runs the task when it was running, mirroring launchd where Install already boots the agent out and back in.
    cmdUninstall called mgr.Stop before mgr.Uninstall, so the stop acte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
2026-10-07 fix(relay): only unlink a stale socket, never a live one (#27)
    listenSocket unconditionally os.Remove'd the socket path before binding, which does not distinguish a stale path a crash left behind from the inode a live relay is still serving.
    A unix bind fails on any pre-existing socket file, so the unlink is needed to recover a leftover path, but deleting a live relay's inode does not stop it: the first relay keeps accepting on the unlinked inode and never sees another producer, so a second relay started on the same path with a different HTTP address silently takes over ingest with no error on either side.
    The fix probes the path before touching it: dial it, remove it only when the dial is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
2026-10-07 test: stabilize two load-sensitive flaky tests (#36)
    TestManySessionsStayResponsive used a fixed 60s wall-clock budget that
    overran under the concurrent -race load of a full `make check` run while
    passing in isolation. The budget exists to catch an algorithmic blowup in
    Apply, which would overrun any bound in this range by orders of magnitude,
    so widen it generously and account for -race overhead explicitly.
    TestSlowShutdownDoesNotUnlinkTheNextRelaysSocket slept a fixed 50ms to let
    relay A accept the stall connection before shutdown. Under CPU contention
    50ms was not always enough. The accept need not be observed before cancel:
    shutdown closes the socket listener only after the run loop ret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
2026-10-07 fix(tracker): scope the reap to the syncing provider so foreign syncs spare unattributed sessions (#21)
    Reconcile's removal pass deleted every session with no provider, whatever
    producer's sync triggered it. That reap was added (85fcf28) because the Claude
    Code hooks sent no provider and undispatched pre-warmed workers leaked. But the
    same commit also made the hooks send --provider, closing the leak at its
    source, so the reap now only hits the wrong target: the RFC 13 and readme
    reference producers — the curl one-liner, the stoplight_run shell wrappers, the
    Go snippet — all omit provider, and the Claude Code poller runs by default, so
    any of them showed red for at most one 20s poll and t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
2026-10-07 fix(service): quote schtasks relay args and make install validation live (#24)
    createArgs joined the relay arguments into the /TR string with a raw space and quoted only the binary path, so a value with a space in it was corrupted when the relay read the command line back. install --ble-name "Stoplight A4" registered a task that ran relay --ble-name Stoplight A4; the flag parser took the name as "Stoplight" and dropped "A4" as a positional, so the service connected to the wrong light, and a double quote in a name corrupted the whole string.
    cmdInstall also called transportChoice.validate with only the Bluetooth flags set, but every branch of validate required --virtual or --serial, which in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
2026-10-07 fix(adapter): poll interactive sessions by status, not just state (#19)
    `claude agents --json` reports interactive sessions with a `status` field
    (busy/idle/waiting) and no `state`. The poller decoded `state` only, so
    `eventForState("")` failed and the unknown-state fallback re-declared every
    open interactive session as started on every poll, flipping a hook-delivered
    red or green back to yellow within one poll interval.
    Decode both fields. `eventForEntry` prefers `state` where present — the two
    can disagree (blocked sessions still read status=idle) and state is the
    richer signal — and falls back to `eventForStatus` for the interactive
    sessions that omit state. An empty field now defers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
2026-10-07 fix(ble): retry a transient adapter enable error (#22)
    enableAdapter ran Enable inside a sync.Once and cached the classified result for the life of the process. A transient failure -- the radio switched off, or a first Enable that outlasted its wait -- was pinned forever, so every later Connect returned the stale error without calling Enable again.
    The relay runs as a login item (stoplight install --ble) and can start while Bluetooth is off, or before the user answers the one-time permission prompt. The sync.Once then latched ErrUnavailable or "did not respond in time" and the light was never found until the relay restarted, contradicting ErrUnavailable's promise that switching Bluetooth on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
2026-10-07 fix(relay): resend a lost or stale frame instead of waiting for a change (#26)
    The relay transmitted only when the tracker changed or on a
    disconnected-to-connected edge, so three gaps left the lamp wrong until
    the next state change.
    A Send that failed was logged and forgotten. The transport contract says
    an error means the frame was lost, not that the link is dead, so a
    transient write error that left the link up held the previous colour
    until the tracker next moved.
    A light power-cycled or carried out of range and back could return with
    no Connect from this relay and no edge the loop could see, so it sat on
    its boot state while Connected still reported true.
    After the first connect noth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
2026-10-07 fix(firmware): wake screen on button press and expire the red hold (#28)
    The button could not wake a blanked screen. togglePin and advance call wake() when asleep, but loop() updates lastFrameAt only on a received frame, never on a button event. Step 4 of the same loop then re-blanks the screen SCREEN_IDLE_MS after the last frame, undoing the wake the press just performed. Treat a handled press as activity by setting lastFrameAt = now, so a woken screen stays up for a fresh idle interval.
    A red hold never expired. holding_ was set in applyFrame but cleared only by a rotation or a manual advance, never by its own deadline. A lone red session, or any single session, can never rotate, so the f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
    [stoplight.ino, test_main.cpp]
2026-10-07 fix(serial): write off the mutex and open the port raw with O_NOCTTY (#29)
    Send held t.mu across t.port.Write. On darwin the Go runtime does not poll a character device, so a Write to a board that has stopped draining its CDC queue blocks in the kernel with no deadline. Connected and Close take the same mutex, so a wedged write froze the relay's connection poll, `stoplight status`, and shutdown behind one stuck frame. The BLE transport's Connected comment names this bug and says it must not be copied.
    The port was also opened with a bare os.OpenFile(path, O_RDWR, 0): no O_NOCTTY and no termios. A session leader with no controlling terminal adopts the port as its controlling tty, so an unplu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
2026-10-07 fix(firmware): refuse a garbled frame instead of keeping a stale colour (#30)
    parseFrame returned true whenever it saw an opening brace, so a truncated frame glued to the next one at a lost newline, {"color":"yellow","sess{"color":"green",...}, parsed as the dropped frame's leading colour and lost the fresh frame. Send-on-change then held the stale lamp until the next state change.
    The parser already distinguishes a cut session array from a closed one; it did not do the same for the top level object. parseFrame now tells TRUNCATION from GARBLE by where the grammar fails: a cut line runs out at the buffer NUL and is still salvaged for the lamps, while a line that fails on a character the gra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
    [test_main.cpp]
2026-10-07 fix(protocol): cap frame fields to the firmware line budget (#31)
    The relay stores session ids up to MaxSessionIDLen (128) and labels up to MaxLabelLen (256), and it emitted those stored values straight into the frame. The firmware line buffer SL_LINE_MAX is 1536 bytes, sized in protocol.h for 8 entries of SL_MAX_ID (40) + SL_MAX_LABEL (48) at ~145 bytes each. A worst-case frame of 8 entries at the storage caps encodes to ~3541 bytes, more than twice the budget.
    A line over SL_LINE_MAX is not truncated, it stops parsing as a session list, so the device discards the list and salvages only the colour. Because frames are sent only on change, every later frame is oversized too and the screen ho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
2026-10-07 docs: re-sync readme and rfc with the committed code (#35)
    The two documents a stranger reads first drifted from the code since their first commit. This brings every factual claim back in line with the code on the dev base.
    BLE. The readme called BLE unimplemented and the device wired-only. BLE ships on both ends (internal/transport/ble, firmware/stoplight/blelink.cpp) with `--ble` and `--ble-name` flags on the relay and on install. The readme and rfc now describe serial and BLE as two live transports behind one interface.
    Hooks. The Claude Code hook table listed four entries. The adapter has five, including SessionEnd to ended (internal/adapter/claudecode/claudecode.go). The table and the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
2026-10-07 ci: add a dispatch release flow and PR gates (#38)
    Add a small semantic-release: a workflow_dispatch release that runs on main
    only, reads Conventional Commit prefixes since the last tag to pick the next
    version (feat -> minor, fix and the rest -> patch, ! or BREAKING CHANGE ->
    major), builds the binaries for linux/darwin/windows on amd64 and arm64, tags,
    and cuts a GitHub Release with auto-generated notes. The first release, with
    no prior tag, starts at v0.1.0. A dry_run input computes and builds without
    tagging or publishing.
    The versioning is a plain shell step, not a third-party action, so what ships
    is what the file says. The binary learns its version through a new `stoplight
    version`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
2026-10-08 feat(firmware): enter standby and clear the lamps when the BLE link drops (#40)
    * feat(firmware): enter standby and clear lamps when the BLE link drops
    A device left powered on with no central connected held its last lamp
    colour forever: a yellow lamp was found still lit ten hours after the
    relay went away, burning LED current and life and running the OLED
    charge pump for a colour that was no longer true.
    Add a Standby module that powers the light down when nothing is driving
    it. The trigger is the absence of both transports: the BLE link is down
    AND no frame has arrived for a grace window. A frame over serial or a
    live BLE link counts as activity, so a serial-driven or connected-quiet
    lig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
    [stoplight.ino, test_main.cpp]
2026-10-08 Revert "feat(firmware): enter standby and clear the lamps when the BLE link drops (#40)"
    This landed on main, but the standby work belongs on dev first per the
    branch flow. Reverting it here; it is re-applied on dev.
    This reverts commit 1ae5f01.
    [stoplight.ino, test_main.cpp]
2026-10-08 ci(release): drop runtime make install, pin cross to linux+windows (#42)
    The cidekar-anvil runner image now ships make (added to the default
    Firecracker rootfs), so the apt-get install step is obsolete and also
    failed on the read-only guest rootfs. Remove it.
    Pin the test gate to PLATFORMS="linux windows": the darwin backend of
    tinygo.org/x/bluetooth (cbgo/CoreBluetooth) only compiles on real macOS,
    so cross-vetting GOOS=darwin from the Linux runner fails on undefined
    CoreBluetooth types. darwin will be covered by a separate macOS-runner
    flow; the Makefile default stays linux windows darwin for local macOS builds.
